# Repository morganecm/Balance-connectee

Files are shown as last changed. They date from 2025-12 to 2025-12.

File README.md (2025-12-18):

# Balance connectée

## Project description

L'objectif du projet est de concevoir une balance connectée permettant de peser une ruche d'abeille, afin que son propriétaire puisse suivre sa progression à distance : si le poids augmente, la ruche produit du miel.

## Groupe de projet 
Morgane CAM m1cam@enib.fr 

Reine CHAMES r24chames@enib.fr

Zakaria BOUMLINE z3boumli@enib.fr

Hassan ROUMANI h3rouman@enib.fr

Hussein IBRAHIM h3ibrahi@enib.fr

Aymane BAHSSAIN a3bahssa@enib.fr

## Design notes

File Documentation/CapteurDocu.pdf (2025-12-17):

Analyse et correction des erreurs de mesure d’une balance connectée

Avant de commencer le projet, cela sera utile si vous regardez des exemples de balances connectées afin d’avoir une idée globale du sujet.

Ensuite, le problème que j’ai rencontré est que les valeurs affichées ne sont pas correctes, car le capteur de force n’est pas bien positionné. Par conséquent, je capte des valeurs erronées.

Il est donc nécessaire de concevoir un design mécanique adéquat pour bien positionner les capteurs.

Après cela, vous pouvez tester le système, soit avec Arduino (comme je l’ai déjà fait, même si les valeurs reçues ne sont pas correctes), soit avec un ESP32.

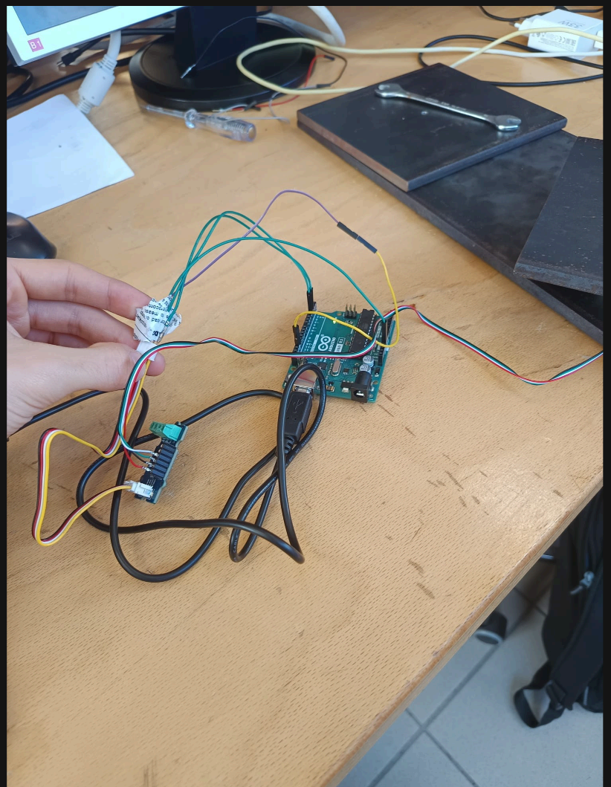
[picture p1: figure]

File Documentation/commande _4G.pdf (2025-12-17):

Connexion et test du module 4G sur Raspberry Pi

Dans le cadre de la connexion d’un module 4G au Raspberry Pi, plusieurs commandes ont été exécutées afin de vérifier la détection du module et d’établir la communication.

Tout d’abord, une connexion distante au Raspberry Pi a été réalisée via le protocole SSH :

ssh rpi@192.168.50.114

Ensuite, la commande suivante a permis de vérifier que le module 4G est bien reconnu par le système via le bus USB :

lsusb

Après cela, la présence des interfaces série créées par le module a été vérifiée :

ls /dev/ttyUSB*

Une fois le port série identifié, une communication directe avec le module 4G a été établie à l’aide de l’outil minicom, en se connectant au port série correspondant :

sudo minicom -D /dev/ttyUSB2

Enfin, une commande AT a été envoyée au module afin de vérifier l’état de la carte SIM :

AT+CPIN?

Cette commande permet de confirmer si la carte SIM est correctement insérée et prête à être utilisée.

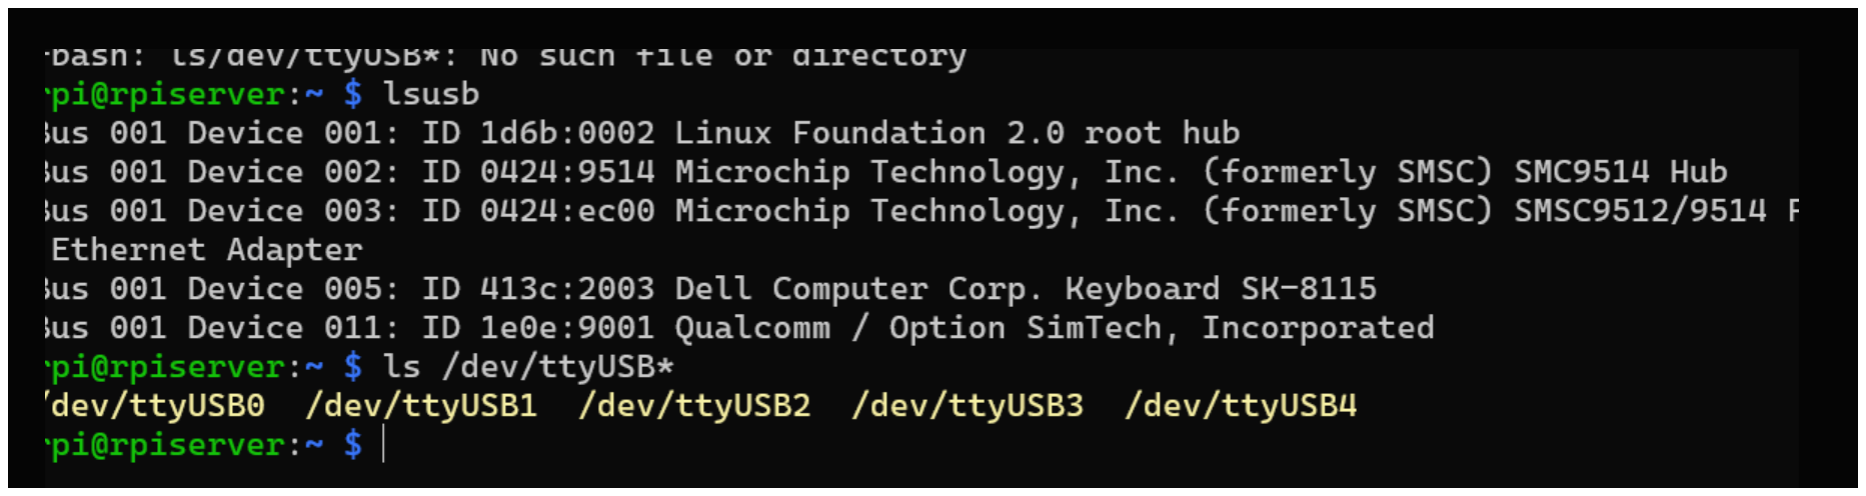
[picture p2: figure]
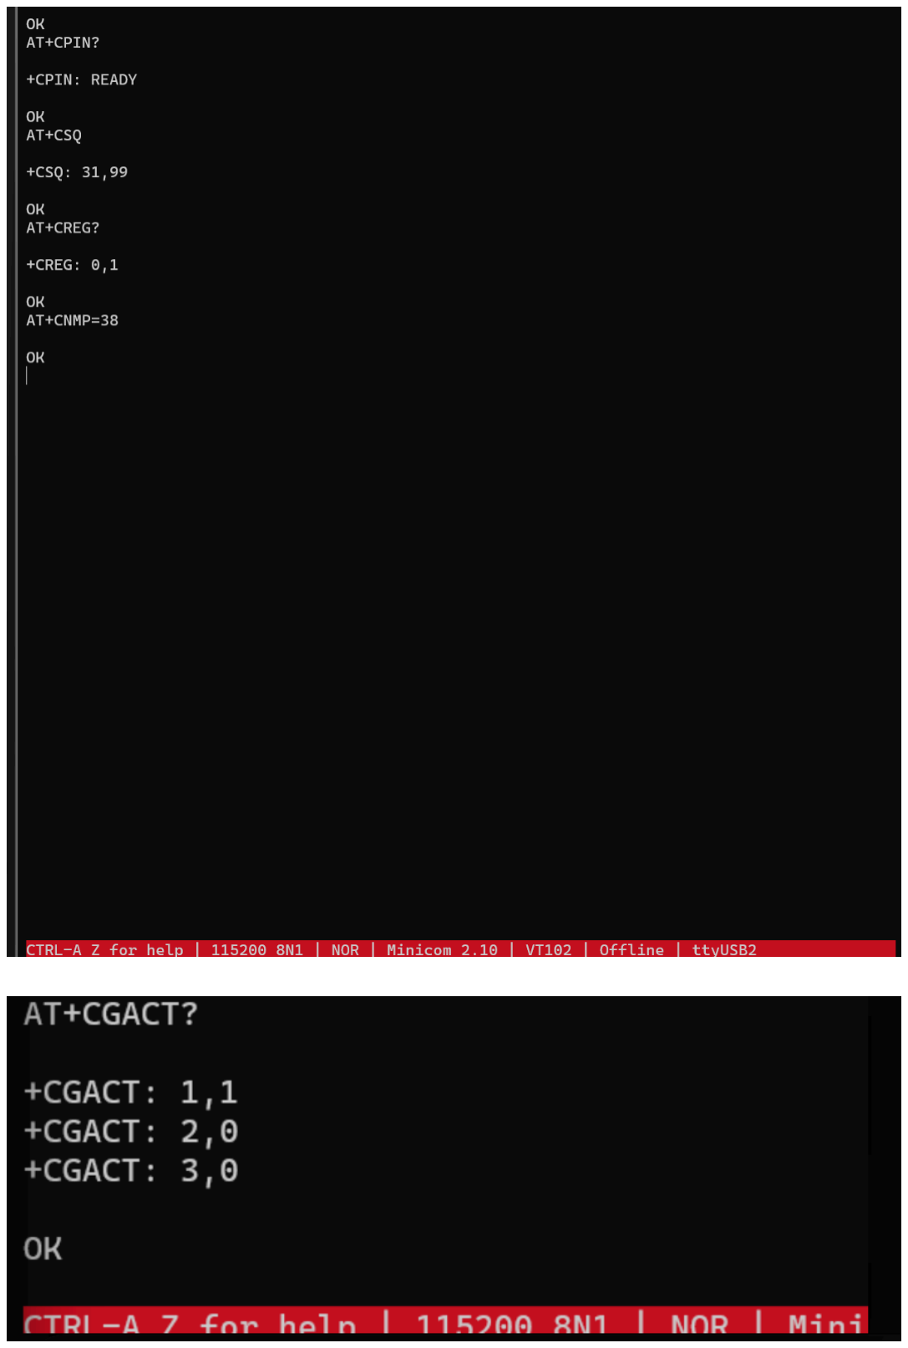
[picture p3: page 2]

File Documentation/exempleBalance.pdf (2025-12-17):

# Une ruche connectée

Au réseau SigFox, avec carte Arduino UNO

### SOMMAIRE

LES CONTRAINTES | page 3
L’ASSEMBLAGE DES ELEMENTS | page 5
LES CAPTEURS UTILISES | page 7
CHOISIR UN RESEAU | page 19
PROGRAMMER LES CAPTEURS | page 24
RECUPERER LES DONNEES | page 41
CHOISIR LES COMPOSANTS | page 51

Jean-Paul Bricard et Sébastien Marcilly

# Une ruche connectée

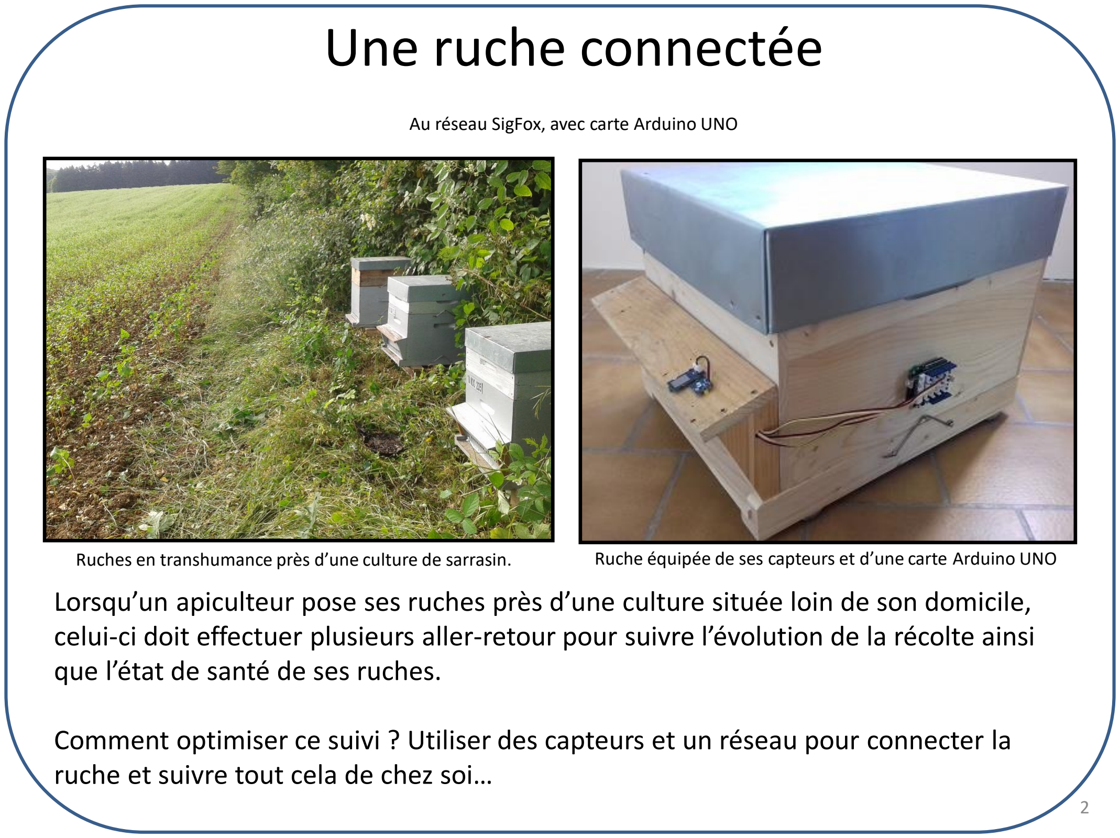
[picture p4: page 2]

Au réseau SigFox, avec carte Arduino UNO

Ruches en transhumance près d’une culture de sarrasin.
Lorsqu’un apiculteur pose ses ruches près d’une culture située loin de son domicile, celui-ci doit effectuer plusieurs aller-retour pour suivre l’évolution de la récolte ainsi que l’état de santé de ses ruches.

Comment optimiser ce suivi ? Utiliser des capteurs et un réseau pour connecter la ruche et suivre tout cela de chez soi…

Ruche équipée de ses capteurs et d’une carte Arduino UNO

# Une ruche connectée

Les contraintes liées à une ruche

Diagramme des cas d’utilisation

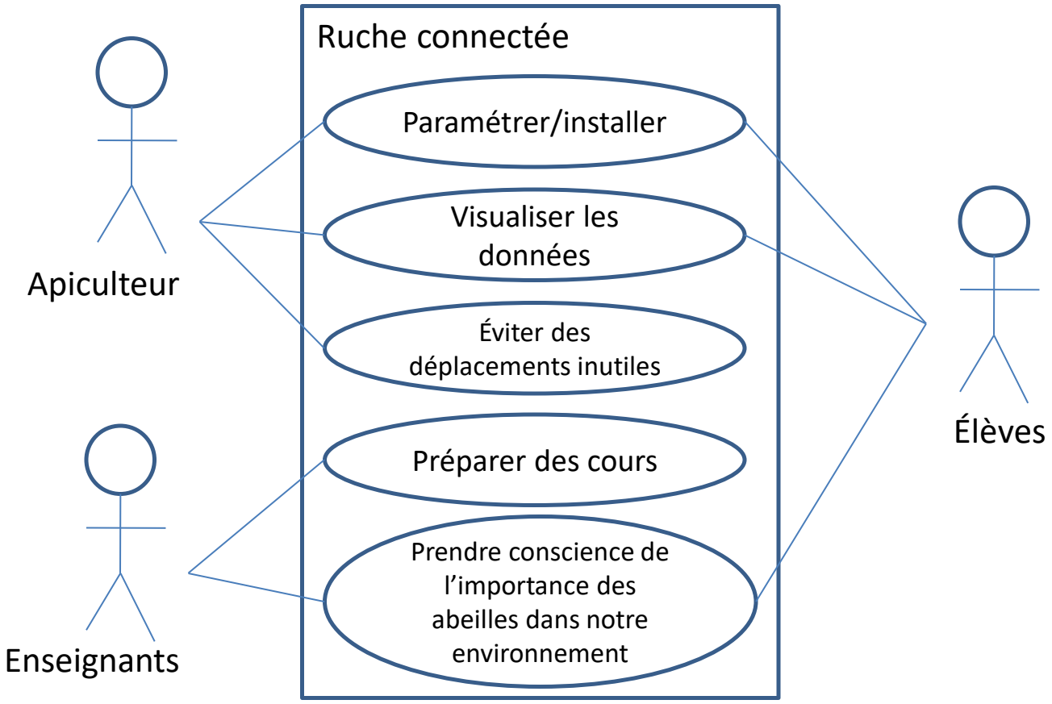
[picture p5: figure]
Ruche connectée; Paramétrer/installer; Visualiser les données; Éviter des déplacements inutiles; Préparer des cours; Prendre conscience de l’importance des abeilles dans notre environnement; Élèves; Apiculteur; Enseignants

# Une ruche connectée

Les contraintes liées à une ruche

Diagramme de contexte; Ruche connectée; Doit pouvoir obtenir les données des capteurs et les envoyer sur un réseau sans fil.; Météo; Doit résister aux intempéries et aux variations de température; Énergie; Doit être autonome et économique en énergie; Communication; Doit utiliser un réseau permettant une connexion en pleine nature; Abeilles; Doit respecter les abeilles; Environnement; Doit respecter le développement durable; Apiculteur; Permet à l’apiculteur de connaître les valeurs des capteurs de la ruche et l’état de santé de la colonie

# Une ruche connectée

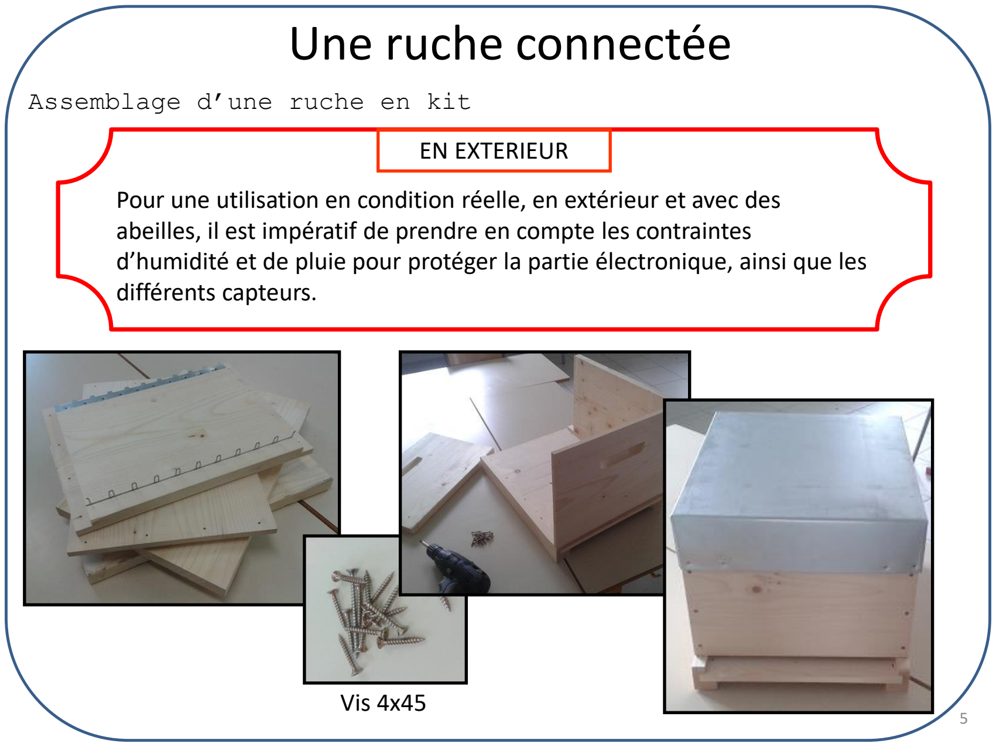
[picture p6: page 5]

Assemblage d’une ruche en kit

Vis 4x45

EN EXTERIEUR

Pour une utilisation en condition réelle, en extérieur et avec des abeilles, il est impératif de prendre en compte les contraintes d’humidité et de pluie pour protéger la partie électronique, ainsi que les différents capteurs.

# Une ruche connectée

Assemblage du auvent de la ruche

Perçage des cotés pour la fixation sur la ruche. Vis 4x60

Ø 8, profondeur 20mm pour passer la tête de vis,
Ø 4, traversant pour passer la vis

Fixation du auvent sur les cotés. Vis 4x30

# Une ruche connectée

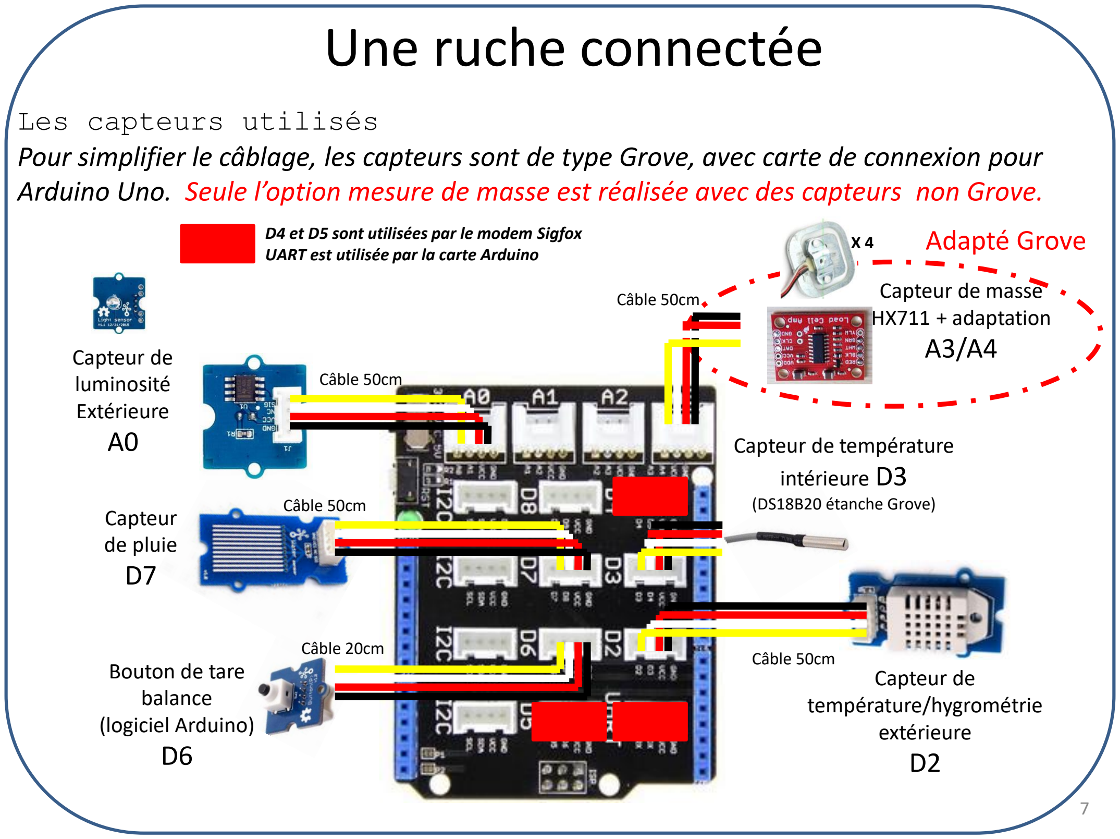
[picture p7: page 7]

Capteur de
luminosité
Extérieure
A0

Capteur de
température/hygrométrie
extérieure
D2

Capteur de masse
HX711 + adaptation
A3/A4

Adapté Grove

Capteur de température
intérieure D3

(DS18B20 étanche Grove)
Capteur
de pluie
D7

Câble 50cm

Câble 50cm

Câble 50cm

Câble 50cm

Les capteurs utilisés
Pour simplifier le câblage, les capteurs sont de type Grove, avec carte de connexion pour Arduino Uno. Seule l’option mesure de masse est réalisée avec des capteurs non Grove.

X 4

Bouton de tare
balance
(logiciel Arduino)
D6

Câble 20cm

D4 et D5 sont utilisées par le modem Sigfox UART est utilisée par la carte Arduino

# Une ruche connectée

La carte Arduino UNO et la carte de connexion Grove

# Une ruche connectée

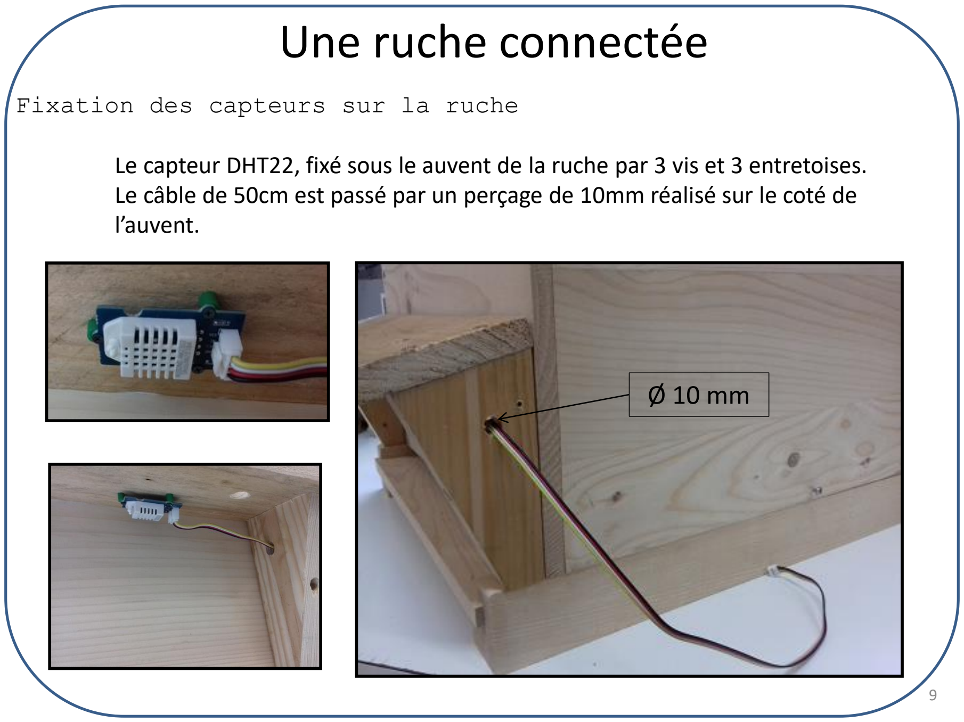
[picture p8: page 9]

Fixation des capteurs sur la ruche

Le capteur DHT22, fixé sous le auvent de la ruche par 3 vis et 3 entretoises. Le câble de 50cm est passé par un perçage de 10mm réalisé sur le coté de l’auvent.

Ø 10 mm

# Une ruche connectée

Fixation des capteurs sur la ruche

Le capteur de pluie, fixé sur le auvent de la ruche par 3 vis et 3 entretoises.
Une extrémité du câble de 50cm est passée par un perçage de 13mm réalisé sur le dessus de l’auvent. L’autre extrémité passe par le perçage de 10mm réalisé sur le coté de l’auvent.

Ø 13 mm

# Une ruche connectée

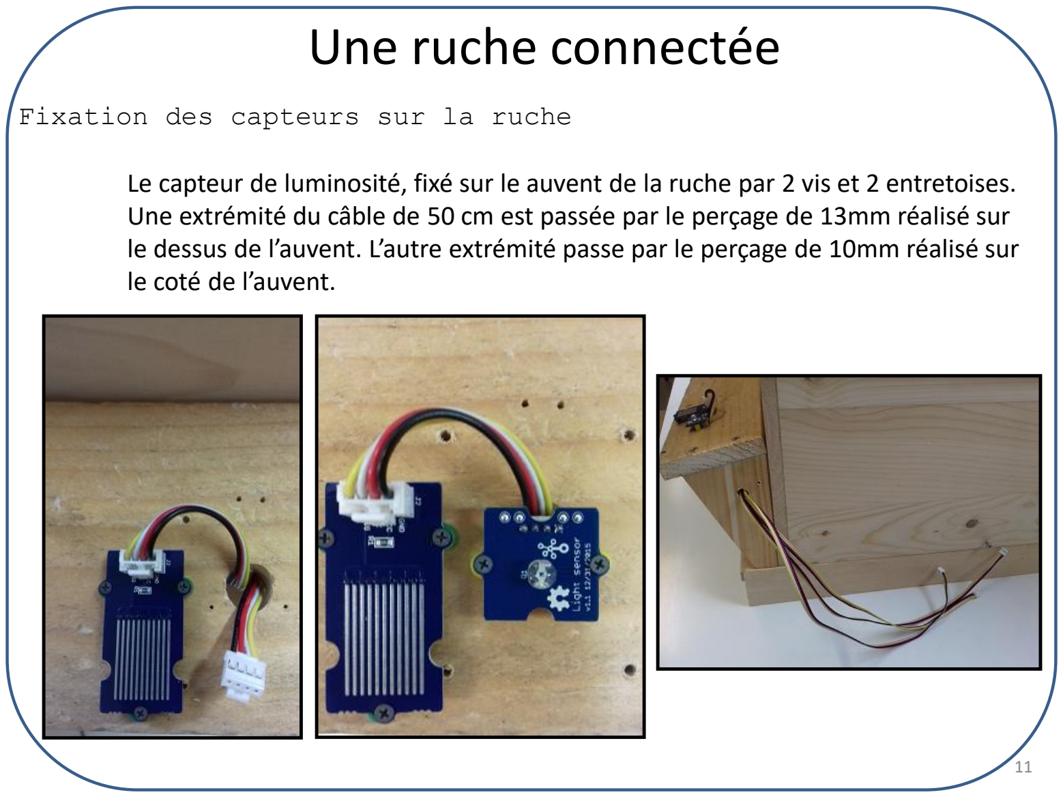
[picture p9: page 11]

Fixation des capteurs sur la ruche

Le capteur de luminosité, fixé sur le auvent de la ruche par 2 vis et 2 entretoises. Une extrémité du câble de 50 cm est passée par le perçage de 13mm réalisé sur le dessus de l’auvent. L’autre extrémité passe par le perçage de 10mm réalisé sur le coté de l’auvent.

# Une ruche connectée

Fixation des capteurs sur la ruche

Le capteur de température intérieure, est à insérer dans la ruche.
Un perçage de 8mm est réalisé dans le couvre cadres pour permettre le passage du capteur entre 2 cadres de la ruche sans gêner la pose du toit.

Ø 8 mm
Entre 2 cadres

# Une ruche connectée

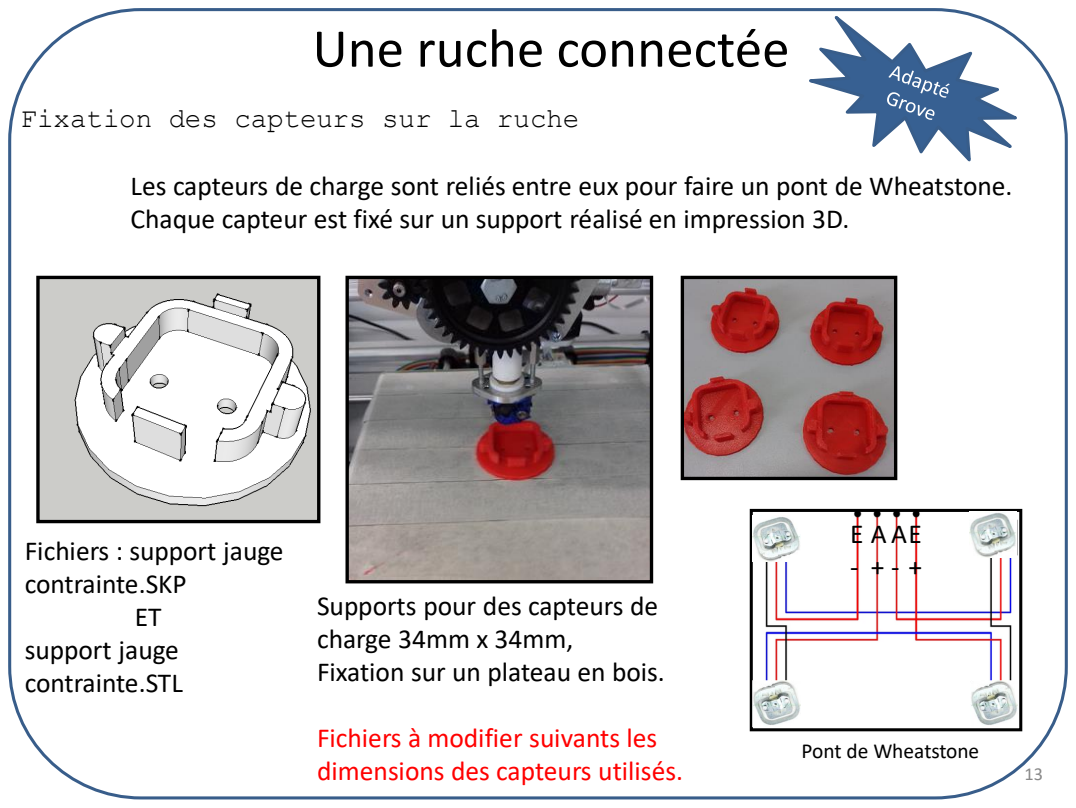
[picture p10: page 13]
ET support jauge contrainte.STL

Fixation des capteurs sur la ruche

Les capteurs de charge sont reliés entre eux pour faire un pont de Wheatstone.
Chaque capteur est fixé sur un support réalisé en impression 3D.

Fichiers : support jauge
contrainte.SKP

Supports pour des capteurs de
charge 34mm x 34mm,
Fixation sur un plateau en bois.

Fichiers à modifier suivants les
dimensions des capteurs utilisés.

Pont de Wheatstone

# Une ruche connectée

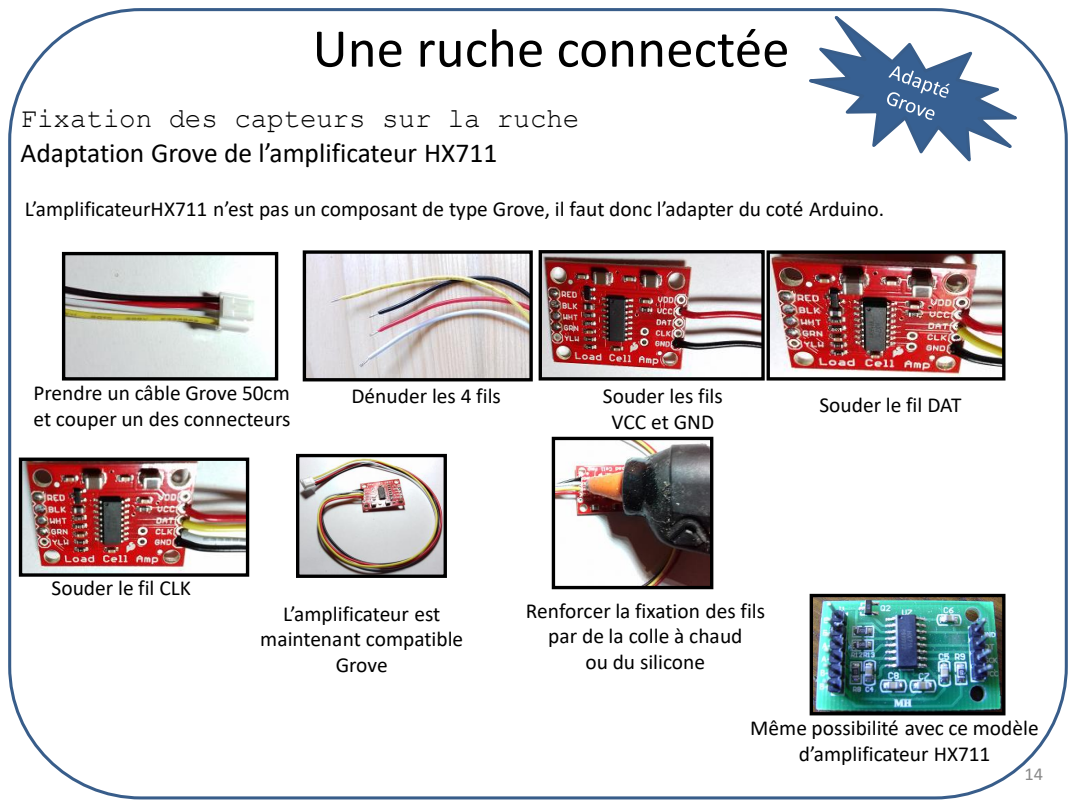
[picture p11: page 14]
Dénuder les 4 fils; Souder les fils; L’amplificateur est maintenant compatible Grove

Fixation des capteurs sur la ruche
Adaptation Grove de l’amplificateur HX711

L’amplificateurHX711 n’est pas un composant de type Grove, il faut donc l’adapter du coté Arduino.

Prendre un câble Grove 50cm
et couper un des connecteurs

Souder le fil DAT

VCC et GND

Souder le fil CLK

Renforcer la fixation des fils
par de la colle à chaud
ou du silicone

Même possibilité avec ce modèle
d’amplificateur HX711

# Une ruche connectée

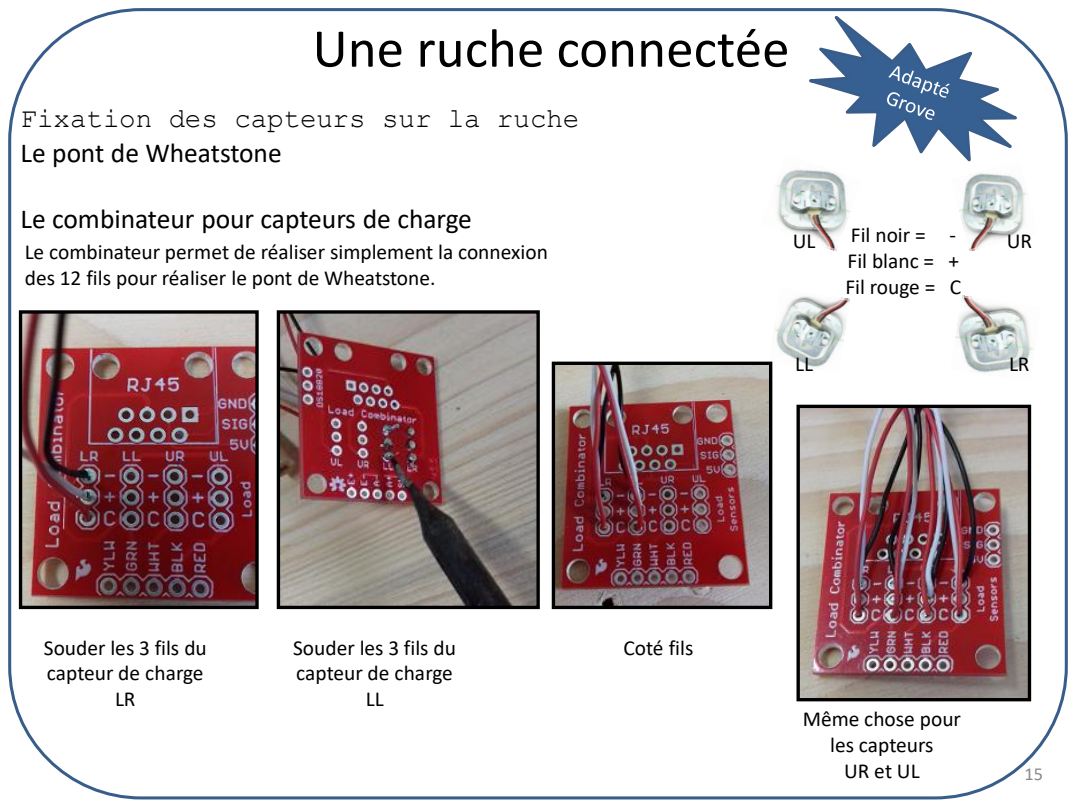
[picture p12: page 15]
UR Fil noir = -; Fil blanc = + Fil rouge = C; Coté fils

Fixation des capteurs sur la ruche
Le pont de Wheatstone

Le combinateur pour capteurs de charge
Le combinateur permet de réaliser simplement la connexion
des 12 fils pour réaliser le pont de Wheatstone.

Souder les 3 fils du
capteur de charge

Même chose pour
les capteurs

# Une ruche connectée

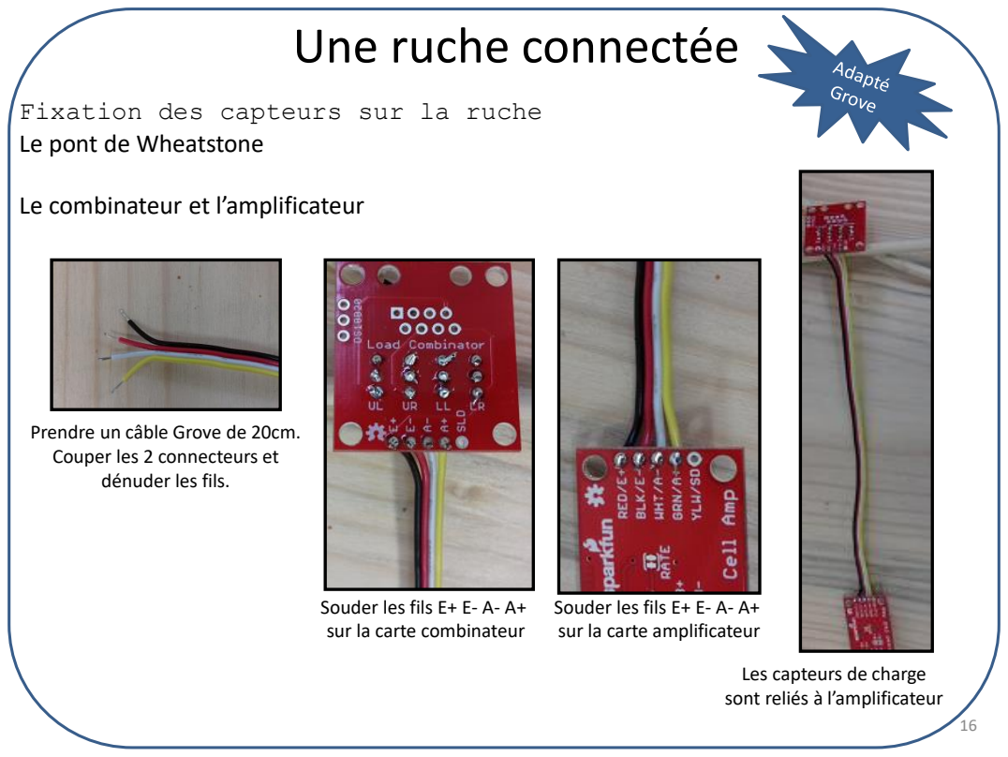
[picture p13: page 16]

Fixation des capteurs sur la ruche
Le pont de Wheatstone

Le combinateur et l’amplificateur

Prendre un câble Grove de 20cm.
Couper les 2 connecteurs et
dénuder les fils.

Souder les fils E+ E- A- A+
sur la carte combinateur

sur la carte amplificateur

Les capteurs de charge
sont reliés à l’amplificateur

# Une ruche connectée

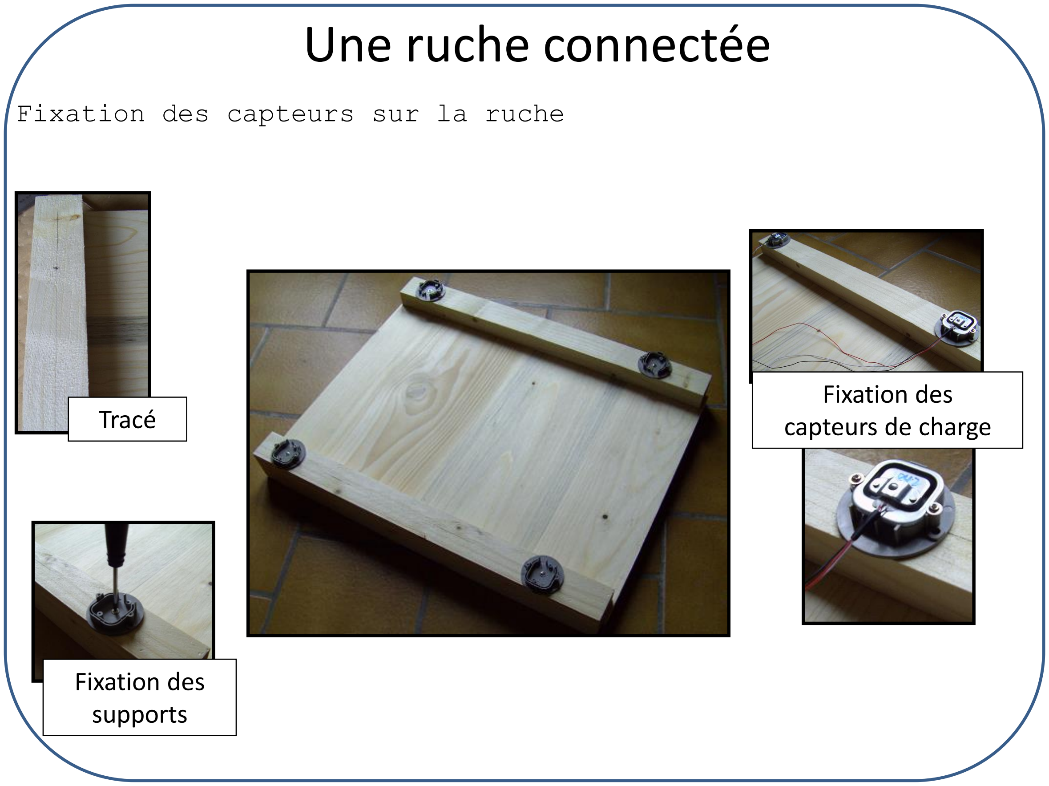
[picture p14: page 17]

Tracé

Fixation des
supports

Fixation des
capteurs de charge

Fixation des capteurs sur la ruche

# Une ruche connectée

Fixe câble

Câble fixé

Pour une utilisation en
extérieur, à placer dans
une boite étanche

Pour une utilisation en
extérieur, protéger les
connexions avec du
silicone.

Fixation des capteurs sur la ruche

Possibilité de placer
les fils des capteurs de
charge dans une gaine
de câble téléphonique,
préalablement fendue
sur la longueur.

Choisir un réseau pour connecter la ruche

# Une ruche connectée

Choisir le bon réseau est un point essentiel pour suivre le travail des abeilles à distance. Voici un comparatif de différentes solutions :
Comparatif des réseaux
Réseau | Avantages | Inconvénient
Sigfox | Consommation réduite, longue portée | Réseau nouveau
GSM | Consommation moyenne Longue portée | Coût élevé
Ethernet | Fiabilité du transfert, Faible coût | Filaire
Zigbee | Consommation réduite, Faible coût | Petite portée
Wifi | Pas d’abonnement | Coût élevé, Petite portée, modem
Bluetooth | Faible coût | Petite portée

Le réseau SIGFOX

Le choix s’est arrêté sur le réseau Sigfox pour plusieurs critères.

Sigfox est une société française, près de Toulouse.
Sigfox a créé un réseau longue portée et à bas débit qui permet la communication de données de taille réduite entre les appareils connectés sans passer par un téléphone mobile. C’est le tout premier réseau de l’IoT ou IdO (Internet des Objets) à avoir été mis en place.

Cette connexion à bas débit entre les objets connectés est possible grâce à sa technologie radio (UNB). Peu énergivore, elle utilise des bandes de fréquence libre de droit disponible pour le monde entier, comme les bandes ISM (Bande industrielle, scientifique et médicale). En Europe, il s’agit de l’ISL à 868 MHz. L’entreprise revendique une couverture de 92 % de la population française.
Le réseau SigFox affiche des performances similaires dans toutes les villes où il est implanté.

Source : http://www.objetconnecte.com/tout-savoir-sur-sigfox/

# Une ruche connectée

La carte AKERU
ou … Comment utiliser le réseau SigFox … ?

http://www.snootlab.com/shields-snootlab/889-akene-v1-fr.html

L’utilisation du réseau SIGFOX se fait grâce à un abonnement au prix de 15€/an (inclus dans le prix d’achat de la carte modem).

Cet abonnement (à renouveler chaque année) permet d’envoyer au maximum 140 messages par jour pendant 1 an. Ce qui revient à 1 message par 10 min.

Cette carte est basée sur une carte Arduino Uno.

Il faut toujours brancher l'antenne avant d'alimenter la carte (sinon l'énergie normalement dissipée
dans l'antenne sera convertie en chaleur dans le modem et peut le détruire).

Les broches D4 et D5 de la carte Arduino lui sont réservées (Rx/Tx)

# Une ruche connectée

http://forum.snootlab.com/viewforum.php?f=51

Toutes les explications techniques sont sur le forum officiel :

Le Shield AKENE pour Arduino Uno
ou … Comment utiliser le réseau SigFox … ?

http://www.snootlab.com/shields-snootlab/889-akene-v1-fr.html

L’utilisation du réseau SIGFOX se fait grâce à un abonnement au prix de 15€/an (inclus dans le prix d’achat de la carte modem).

Cet abonnement (à renouveler chaque année) permet d’envoyer au maximum 140 messages par jour pendant 1 an. Ce qui revient à 1 message par 10 min.

Cette carte se monte sur les connecteurs de la carte Arduino.

Le câblage des Entrées/Sorties se fait de la même manière que sur la carte Arduino seule. Il faut toujours brancher l'antenne avant d'alimenter la carte (sinon l'énergie normalement dissipée
dans l'antenne sera convertie en chaleur dans le modem et peut le détruire).

Les broches D4 et D5 de la carte Arduino lui sont réservées (Rx/Tx) Transfert des programmes AVEC le shield monté sur la carte Arduino UNO

# Une ruche connectée

http://forum.snootlab.com/viewforum.php?f=51

Toutes les explications techniques sont sur le forum officiel :

Le SHIELD ARM-N8-SIGFOX pour Arduino Uno
ou … Comment utiliser le réseau SigFox … ?

https://www.lextronic.fr/P37770-shield-radio-arm-n8-sigfox.html

Cette carte propose les mêmes fonctionnalités que le Shield AKENE
MAIS le modem utilise les Rx/Tx (D0/D1 ) de la carte Arduino Uno pour communiquer. Pour transférer le programme, il faut impérativement retirer le Shield et le remettre en place après.

# Une ruche connectée

Le choix s’est tourné vers le shield AKENE,

Snootlab permet un achat par les établissements scolaires Le laboratoire est déjà équipé de cartes Arduino Uno, Pas de dépose/repose du shield lors de la programmation

# Une ruche connectée

Programmation des capteurs avec les logiciels

Logiciel Ardublock éducation 1.3
Sont uniquement programmables avec cette version : le capteur de température HD (DHT22), le capteur de lumière et le capteur de pluie.

Logiciel Mblock 3.4.11 + extension TS GROVE 1.3
Mode connecté
Sont uniquement programmables avec cette extension : le capteur de température HD (DHT22), le capteur de lumière et le capteur de pluie.
Mode téléversé
Pour programmer le capteur de température intérieure (DS18B20), le capteur de masse ainsi que le shield AKENE (modem SigFox), il faut ajouter l’extension Ruche GROVE et les bibliothèques Arduino. Cette extension permet de relever les valeurs des capteurs de la ruche et de les envoyer sur le réseau SigFox.
Visualisation de ces valeurs uniquement sur le tableau de bord Actoboard.

Pour aller plus loin, le logiciel Arduino 1.6.9
L’ensemble des capteurs de la ruche ainsi que le modem sont programmables en lignes de code. Les valeurs sont affichées par le moniteur série et/ou sur le tableau de bord Actoboard. Il faut ajouter les bibliothèques Arduino.

# Une ruche connectée

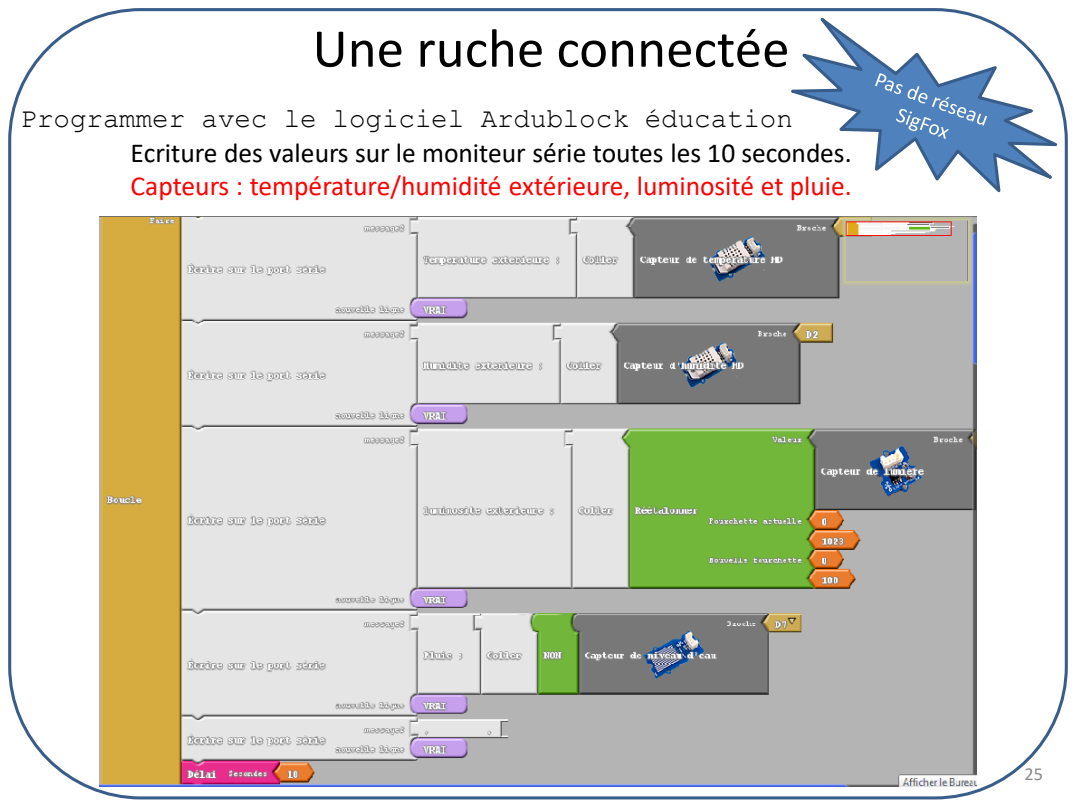
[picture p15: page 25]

Programmer avec le logiciel Ardublock éducation

Ecriture des valeurs sur le moniteur série toutes les 10 secondes.
Capteurs : température/humidité extérieure, luminosité et pluie.

# Une ruche connectée

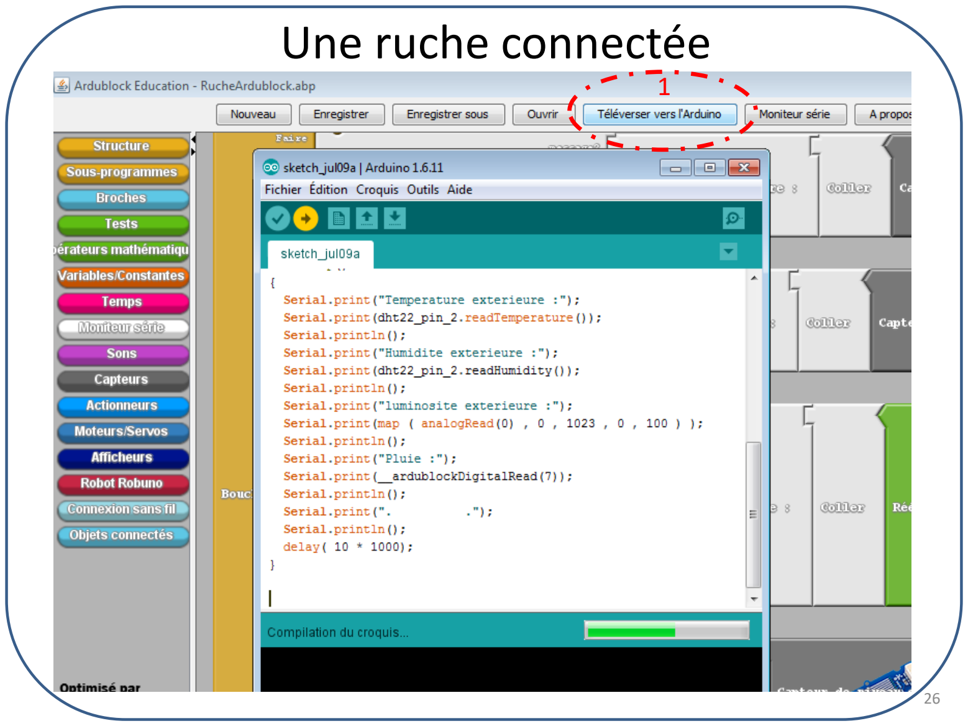
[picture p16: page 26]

1

# Une ruche connectée

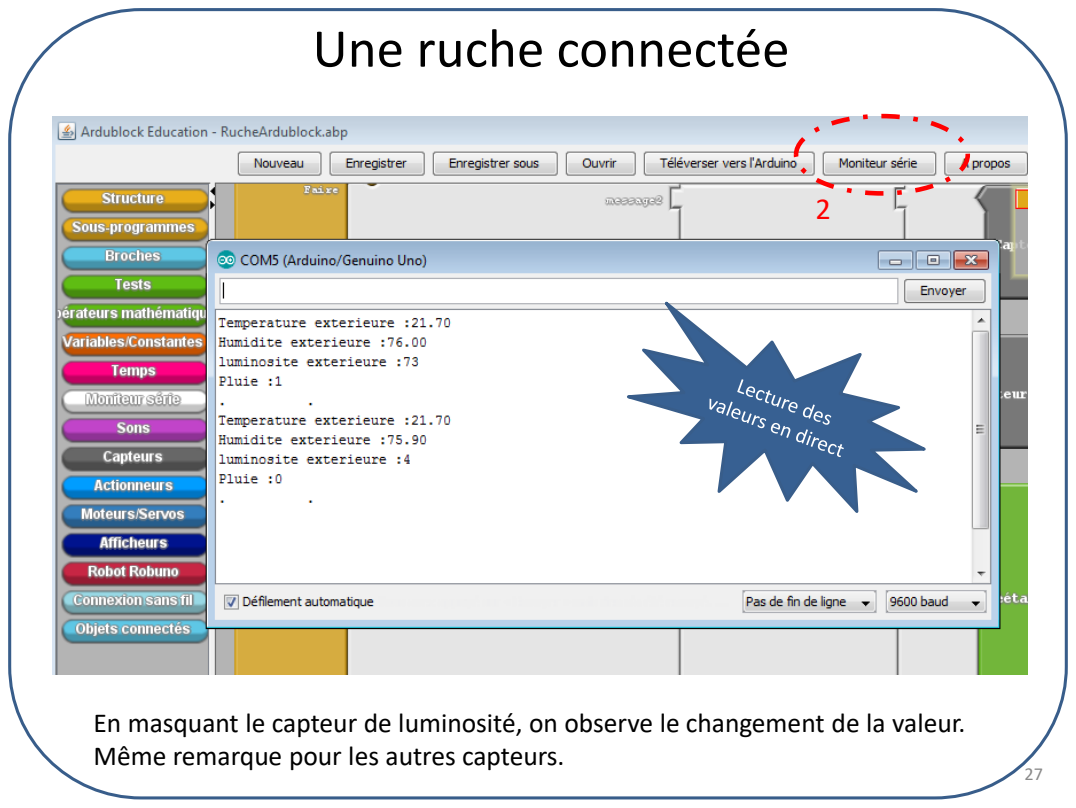
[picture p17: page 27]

En masquant le capteur de luminosité, on observe le changement de la valeur.
Même remarque pour les autres capteurs.

# Une ruche connectée

Logiciel IDE Arduino 1.6.9 et ajout des bibliothèques
Pour rendre la bibliothèque du shield Akene compatible avec Mblock, Il faut remplacer le dossier Arduino du répertoire mblock par le dossier Arduino contenu dans le dossier « A remplacer dans Mblock ».

Ce remplacement permet de mettre Arduino version 1.6.9, au lieu de la version 1.6.5 installée par Mblock.

# Une ruche connectée

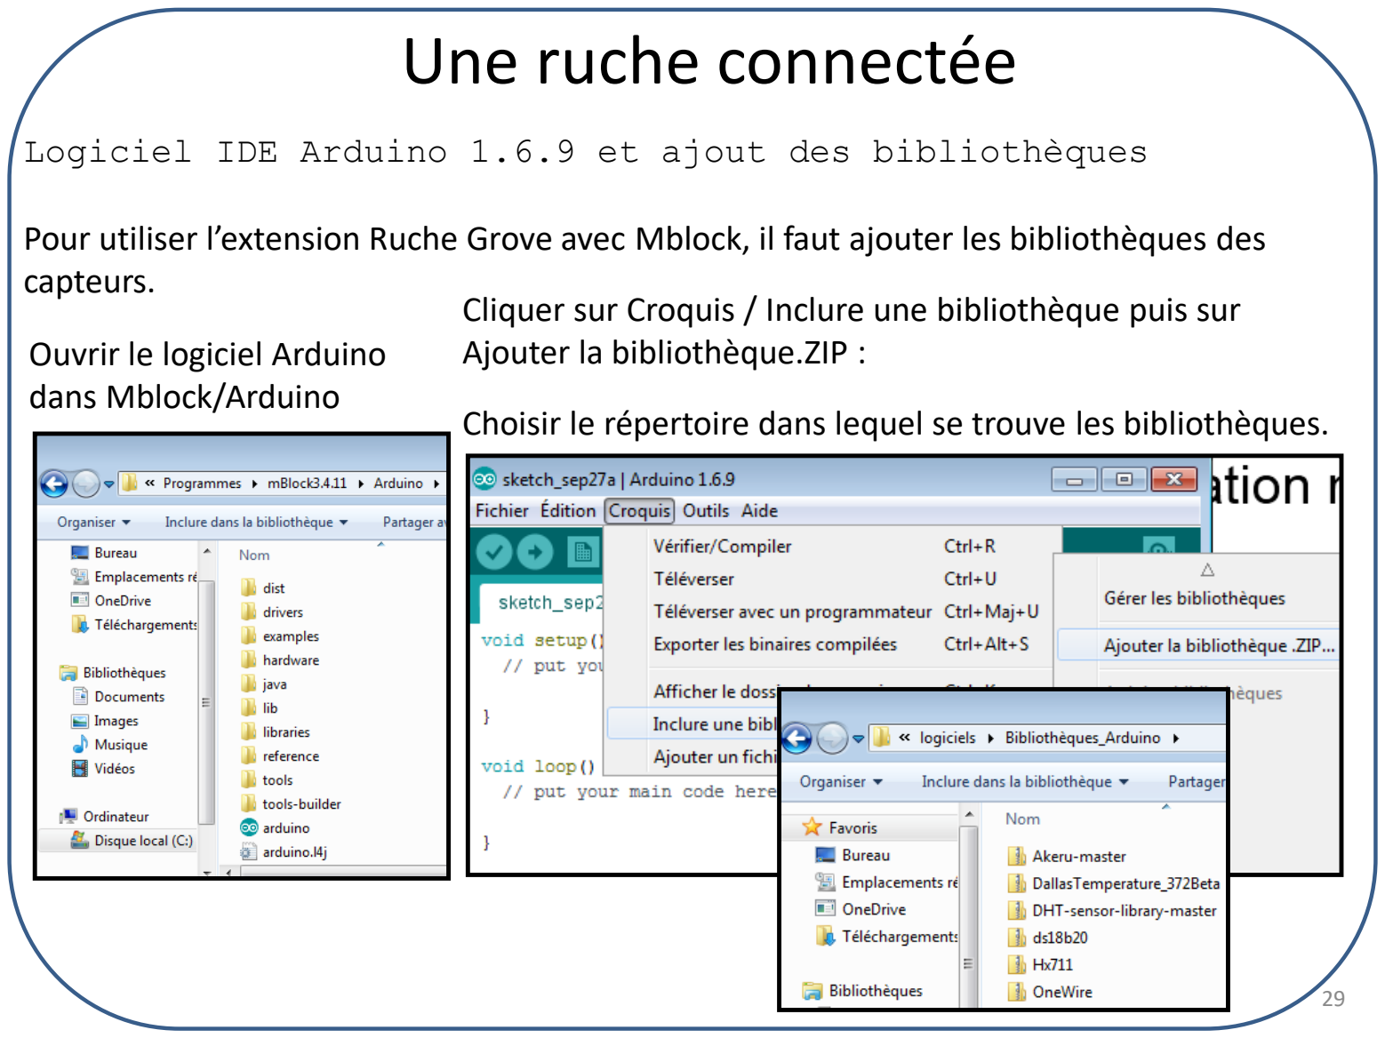
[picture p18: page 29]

Ouvrir le logiciel Arduino dans Mblock/Arduino

Cliquer sur Croquis / Inclure une bibliothèque puis sur Ajouter la bibliothèque.ZIP :

Choisir le répertoire dans lequel se trouve les bibliothèques.

Logiciel IDE Arduino 1.6.9 et ajout des bibliothèques

Pour utiliser l’extension Ruche Grove avec Mblock, il faut ajouter les bibliothèques des capteurs.

# Une ruche connectée

Ajout des extensions Mblock
Ajouter l’extension TS GROVE 1.3

Sélectionner l’extension
TS (.ZIP)

Cliquer sur :
Ajouter

Sélectionner (.ZIP)

Cliquer sur :
Gérer les extensions

# Une ruche connectée

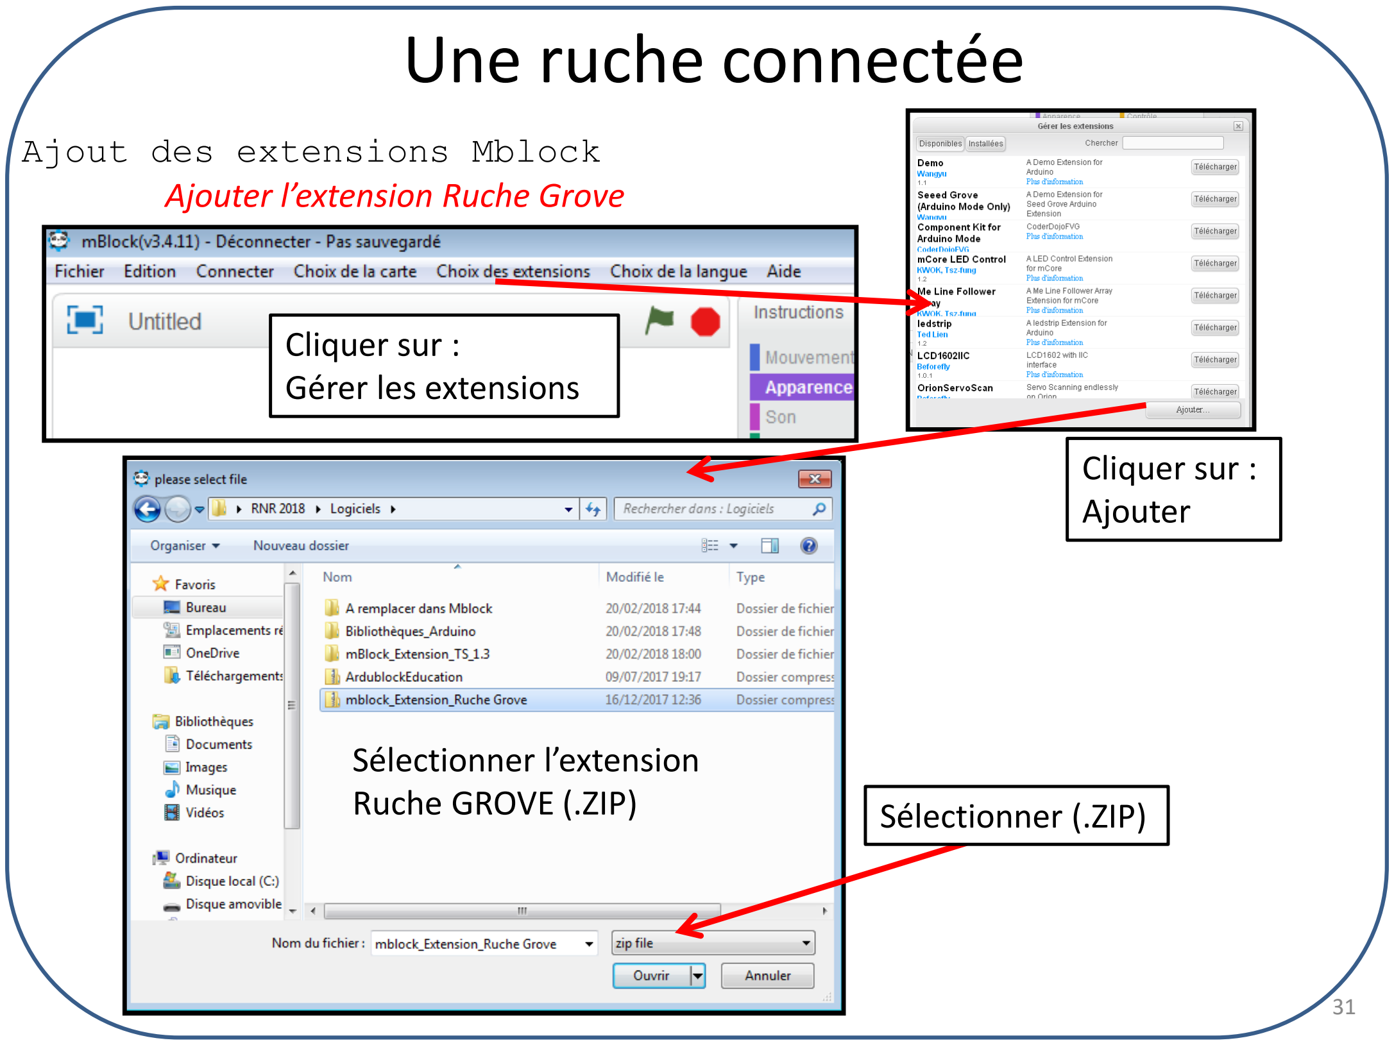
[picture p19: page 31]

Ajout des extensions Mblock
Ajouter l’extension Ruche Grove

Sélectionner l’extension
Ruche GROVE (.ZIP)

Cliquer sur :
Ajouter

Sélectionner (.ZIP)

Cliquer sur :
Gérer les extensions

# Une ruche connectée

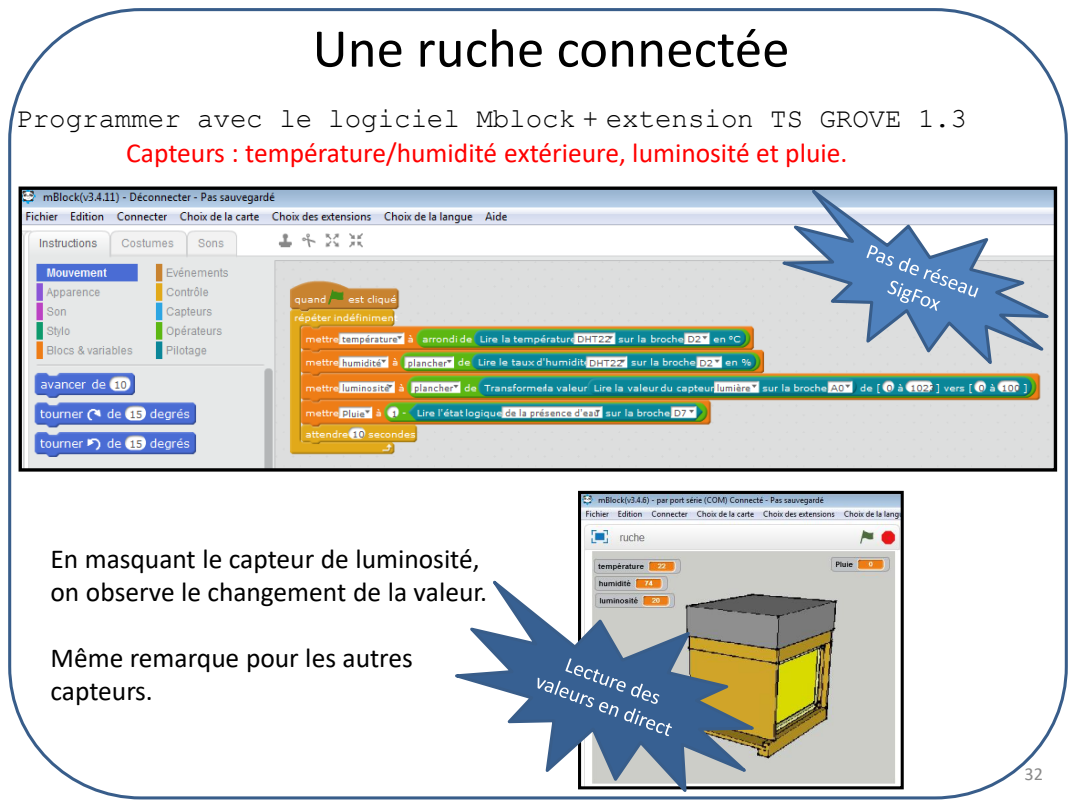
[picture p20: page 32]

Programmer avec le logiciel Mblock + extension TS GROVE 1.3

Capteurs : température/humidité extérieure, luminosité et pluie.

En masquant le capteur de luminosité,
on observe le changement de la valeur.

Même remarque pour les autres
capteurs.

# Une ruche connectée

L’extension Ruche GROVE pour Mblock
Utilisation du réseau SigFox avec Shield AKENE ou carte AKERU

Génère le code Arduino

Initialise le modem
suivant la carte utilisée

Lecture DHT22, sur D2

Lecture DS18B20, sur D3

Lecture capteur luminosité, sur A0

Lecture capteur de pluie, sur D7

Lecture capteur de masse, sur A3

# Une ruche connectée

Envoi capteur DHT22

Envoi capteurs pluie et luminosité et DS18B20 et DHT22 et masse

Le code associé à l’envoi est à recopier dans le format data du tableau de bord Actoboard pour visualiser les valeurs envoyées.

Envoi capteur luminosité

Envoi capteur DS18B20

Envoi capteur pluie

Envoi capteur de masse

Envoi capteurs pluie et luminosité et DS18B20 et DHT22

Envoi capteurs luminosité et DS18B20 et DHT22

# Une ruche connectée

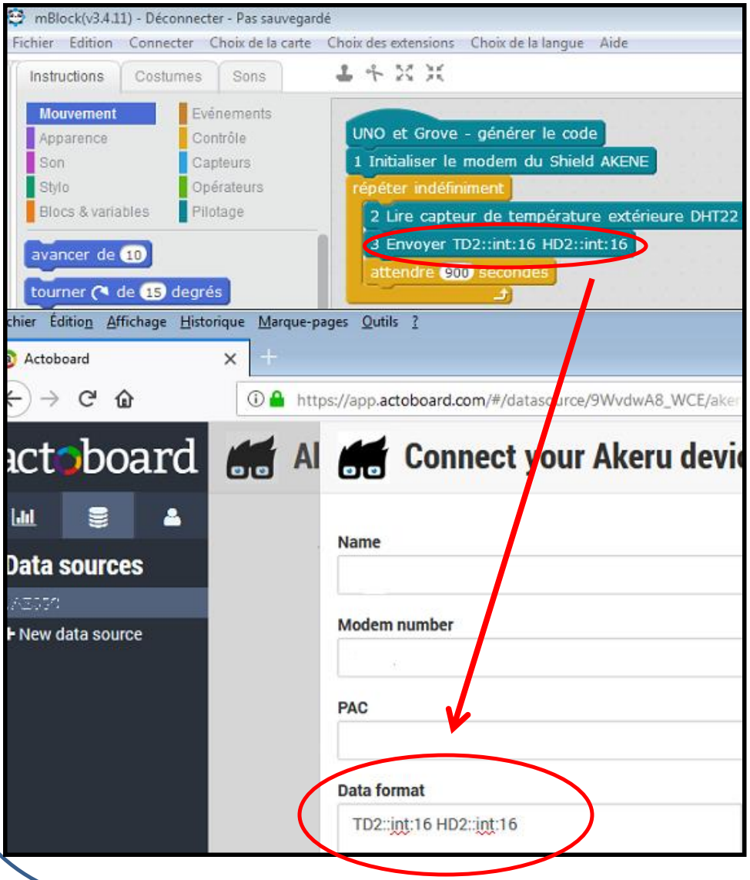
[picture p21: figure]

Correspondance entre la
commande « Envoyer » Mblock et Data format dans Actoboard

# Une ruche connectée

Programme Mblock + extension Ruche GROVE
Utilisation du réseau SigFox avec le Shield AKENE et abonnement Actoboard activé

Envoi des valeurs du capteur DHT22

Envoi des valeurs du capteur de pluie

La ligne de code Data format est complétée sur Actoboard.

Attente de 15min entre chaque envoi (60 x 15 =900)

# Une ruche connectée

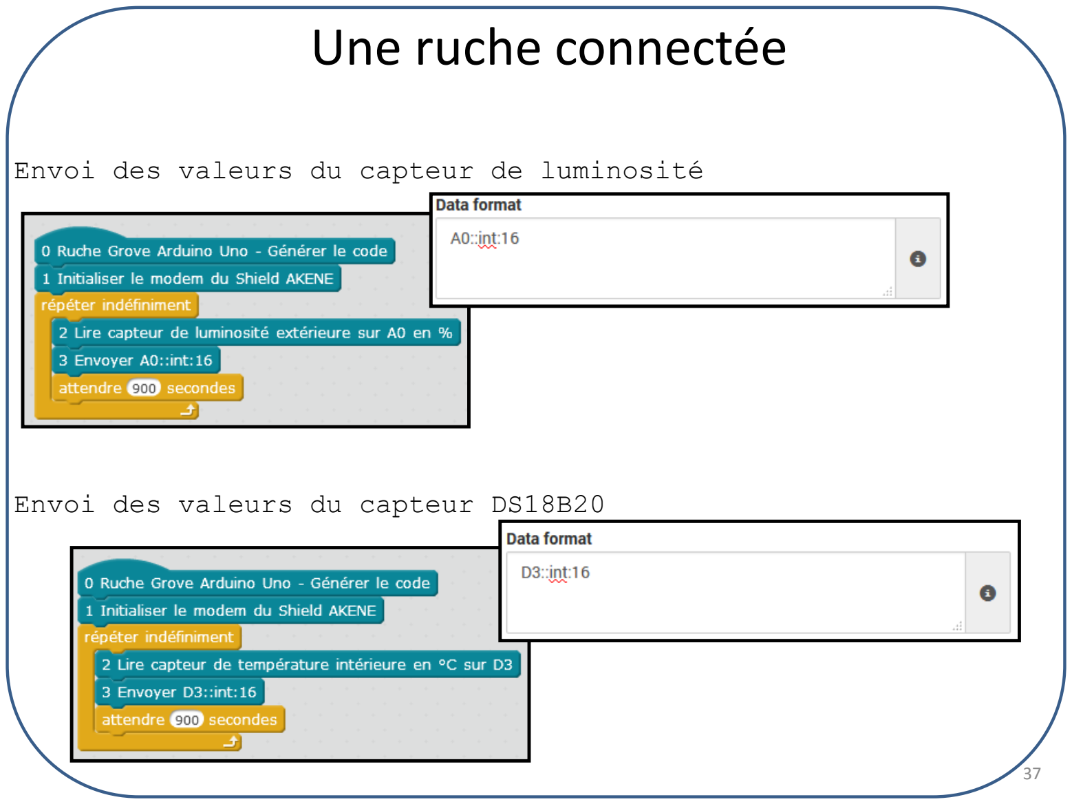
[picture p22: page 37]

Envoi des valeurs du capteur de luminosité

Envoi des valeurs du capteur DS18B20

# Une ruche connectée

Envoi des valeurs du capteur de luminosité et du capteur DHT22

Envoi des valeurs du capteur de masse

La tare de la balance se fait au début du programme. Ensuite par reset de la carte.

# Une ruche connectée

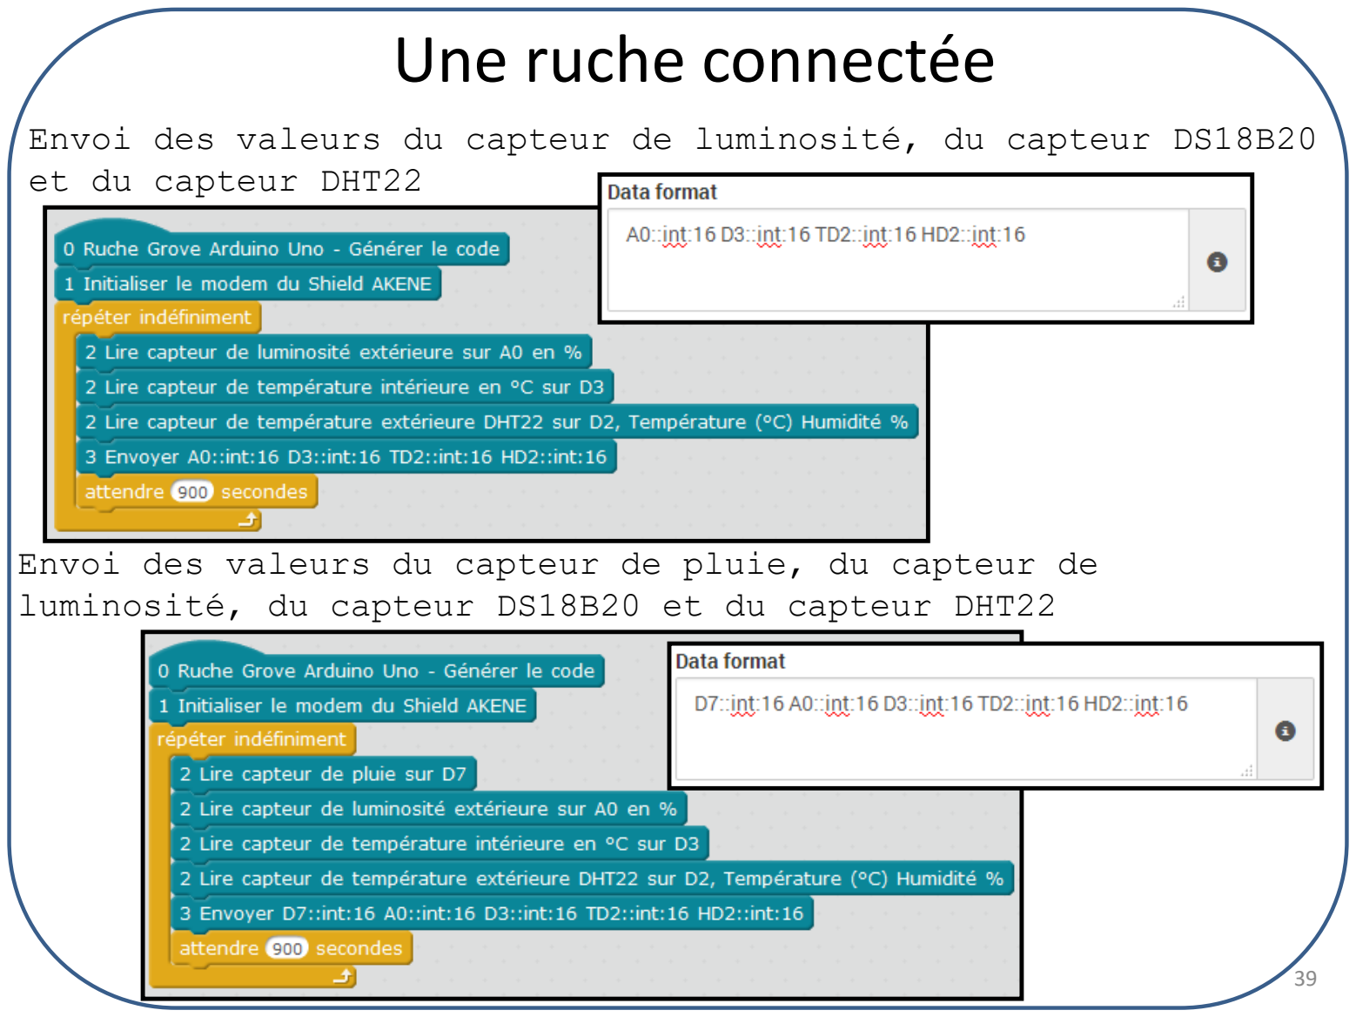
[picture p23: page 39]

Envoi des valeurs du capteur de luminosité, du capteur DS18B20 et du capteur DHT22

Envoi des valeurs du capteur de pluie, du capteur de luminosité, du capteur DS18B20 et du capteur DHT22

# Une ruche connectée

Envoi des valeurs du capteur de pluie, du capteur de luminosité, du capteur DS18B20, du capteur DHT22 et du capteur de masse

La tare de la balance se fait au début du programme. Ensuite par reset de la carte.

Le tableau de bord Actoboard | https://app.actoboard.com/#/
Aide du site | http://www.actoboard.com/docs/

# Une ruche connectée

Créer un compte pour avoir accès aux données envoyées sur le réseau Sigfox par votre modem. Avec le code promo 4K3RU-SN00TL4B

# Une ruche connectée

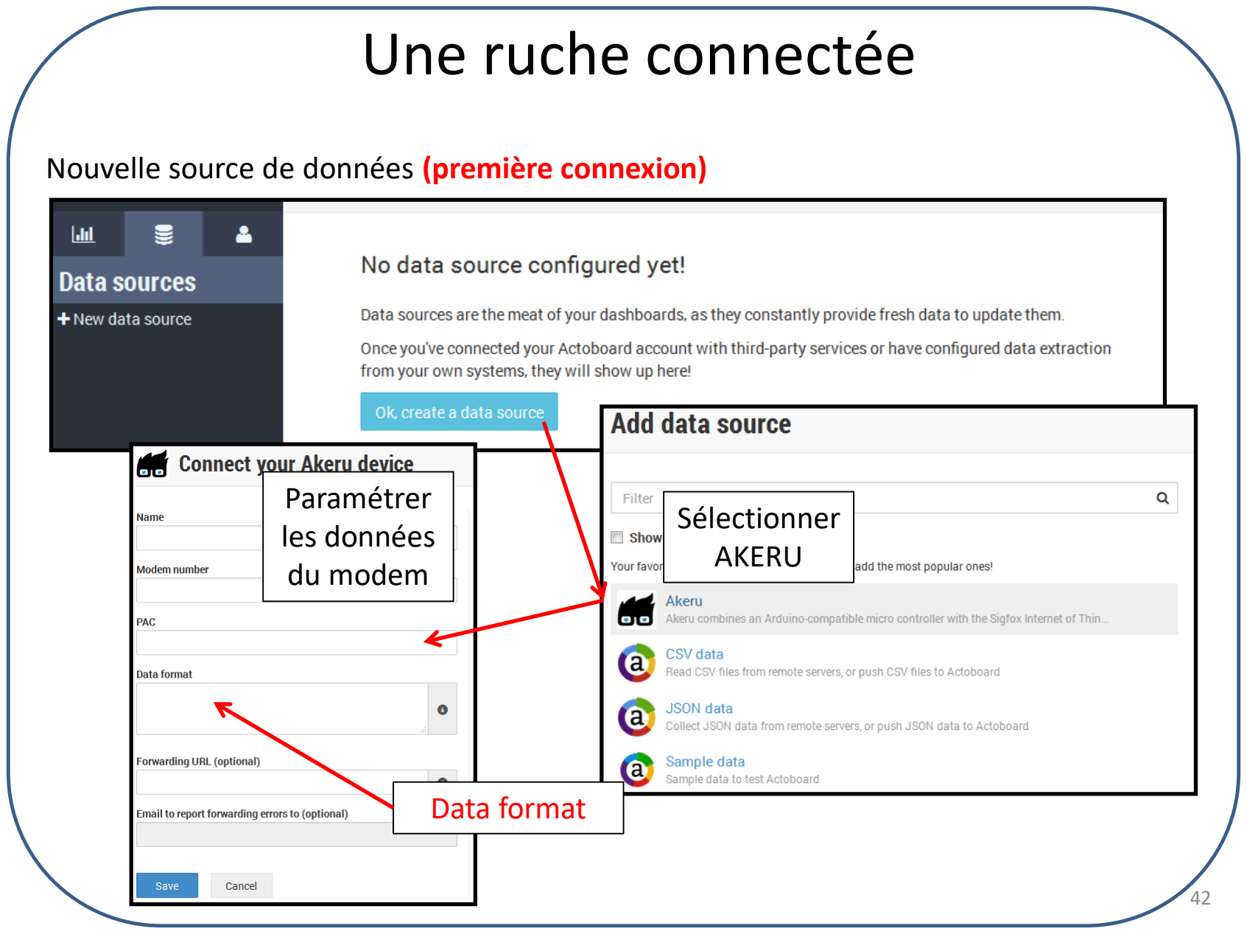
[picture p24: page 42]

Nouvelle source de données (première connexion)

Sélectionner
AKERU

Paramétrer
les données
du modem

Data format

# Une ruche connectée

Nouveau tableau de bord

Nouveau widget (valeur)

Ouvrir le logiciel
Arduino

Ajouter les bibliothèques DHT sensors et AKERU

Cliquer sur Croquis / Inclure une bibliothèque puis sur Ajouter la bibliothèque.ZIP :

Choisir le répertoire dans lequel se trouve les bibliothèques.

# Une ruche connectée

Pour aller plus loin

Programme avec le logiciel IDE Arduino 1.6.9
Utilisation du réseau SigFox avec le Shield AKENE et abonnement Actoboard activé Exemple avec le capteur DHT22, température et humidité extérieure.

String message = humidite + temperature;

# Une ruche connectée

# Une ruche connectée


Connecter la carte Arduino Uno

Sélection
de la carte

Sélection
du port

Pour aller plus loin

Téléverser le programme dans la carte Arduino Uno et visualiser les données sur le

# Une ruche connectée

Pour aller plus loin

Nombre entier

Nombre à virgule

#include <DHT.h>

#include <Akeru.h>

#define DHTPIN 2

#define DHTTYPE DHT22

DHT dht(DHTPIN, DHTTYPE);

#define TX 5

#define RX 4

Akeru Akeru(RX, TX);

void setup()
{
dht.begin();
Akeru.begin();
}

void loop()
{
int humext = dht.readHumidity();
int tempext = dht.readTemperature();

String humidite = Akeru.toHex(humext); String temperature = Akeru.toHex(tempext); String message = humidite + temperature;

Akeru.sendPayload(message); delay(600000);
}

Lignes à remplacer pour
obtenir un relevé à virgule
Dans le programme DHT22_Sigfox_demo.ino | Sur le tableau de bord Actoboard

# Une ruche connectée

Pour aller plus loin

# Une ruche connectée

Inclure la bibliothèque HX711.

En démarrant le moniteur série (9600 bauds), on obtient la masse.
Lors de l’appui prolongé sur le bouton D6,
la tare se fait.

Pour aller plus loin

725g avec la balance de cuisine. La précision est acceptable pour la pesée de la ruche.

Pour rendre le projet autonome en énergie, nous allons remplacer la carte ARDUINO UNO par la carte OLIMEXINO-328. Elle doit être exploitée comme une Arduino Duemilanove.

Elle intègre :

- Une alimentation permissive de 9 à 30V, ou via USB 5V,
- Un circuit de charge intégré qui permet à la carte de fonctionner sur batterie en l’absence
d’alimentation.
- Un design “industriel”, qui promet une plage de fonctionnement de -25 à +85°C, et une bonne immunité aux interférences,
- La capacité de fonctionner en 5V ou 3.3V.

http://www.conrad.fr/ce/fr/product/1195079/Carte-de-developpement-Olimex-OLIMEXINO-328-1-pcs

Panneau solaire 12V/3W
en alimentation

La carte OLIMEXINO-328, UNIQUEMENT AVEC LE LOGICIEL ARDUINO

# Une ruche connectée

Pour aller plus loin

# Une ruche connectée

Fournisseurs et prix donnés à titre indicatif

Coût moyen pour une ruche connectée toutes options 350€


# Une ruche connectée

Il existe des ruche Dadant 10 cadres en kit, avec la hausse de récolte et tous les cadres.

Pour une application pédagogique, on peut s’orienter vers des pièces détachées.
Un fond de ruche en bois, un corps de ruche, un couvre cadres, un toit tôle.

Une ruche 60 à 100 €

Certaines enseignes de bricolage proposent un rayon apiculture,
quelques fournisseurs de matériel apicole en ligne,
https://www.ets-leygonie.net | http://www.apiculture.net | https://www.icko-apiculture.com

Il est possible d’utiliser un ruchette 5 ou 6 cadres. Dans ce cas, la largeur du auvent est à adapter.

Une ruchette 45 €

Fournisseurs et prix donnés à titre indicatif

# Une ruche connectée


Fournisseurs et prix donnés à titre indicatif

Exemples pour une ruche
en ligne 60 à 80 €

# Une ruche connectée

L’électronique 65€ + connectivité au réseau Sigfox 80 €

Capteur de lumière Grove 3,85€

Capteur de température DS18B20 étanche Grove 8€ https://www.gotronic.fr/art-capteur-de-temperature-grove-101990019-23842.htmhttps://www.gotronic.fr/art-capteur-d-humidite-et-de-t-grove-101020019-18964.htm

Capteur de température/humidité DHT22 Grove 15,50€ https://www.gotronic.fr/art-detecteur-de-niveau-d-eau-grove-101020018-19048.htm

Détecteur de niveau d’eau Grove 3,05€ https://www.gotronic.fr/art-detecteur-de-lumiere-grove-v1-1-101020173-25114.htm

https://www.gotronic.fr/art-lot-de-5-cables-grove-50-cm-22297.htm

5 câbles Grove 50cm 4,10€

Fournisseurs et prix donnés à titre indicatif

https://www.lextronic.fr/capteurs-lumiere-couleur/13946-module-grove-capteur-de-lumiere-p.html

https://www.lextronic.fr/temperature-meteo/28936-module-grove-humidite-temperature.html

https://www.lextronic.fr/temperature-meteo/31559-capteur-de-temperature-ds18b20-format-grove.htmlhttps://www.lextronic.fr/temperature-meteo/28928-detecteur-de-niveau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

https://www.lextronic.fr/cordons-connecteurs/28849-cordons-grove-50-cm.html

# Une ruche connectée

Shield AKENE Sigfox 80 €

https://snootlab.com/lang-fr/shields-snootlab/889-akene-v1-fr.htmlhttps://www.gotronic.fr/art-module-grove-base-shield-103030000-19068.htm

Shield Grove Arduino Uno 9,30€

https://www.gotronic.fr/art-carte-arduino-uno-12420.htm

Carte Arduino Uno 19,50€

Fournisseurs et prix donnés à titre indicatif

https://www.lextronic.fr/cartes-arduino-officielles/2474-carte-arduino-uno-dip-rev3.htmlhttps://www.lextronic.fr/shield-fomat-grove/14174-platine-grove-base-shield-v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

# Une ruche connectée

http://www.robotshop.com/eu/fr/combinateur-capteur-de-charge-v11.htmlhttp://www.robotshop.com/eu/fr/amplificateur-cellule-force-hx711.htmlhttp://www.robotshop.com/eu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

Combinateur de capteur de charge 2€

Amplificateur de capteur de charge 10€

4 capteurs de charge 40€

Option mesure de masse 60 €

Bouton Grove 2€
https://www.gotronic.fr/art-module-bouton-grove-111020000-19010.htm

Fournisseurs et prix donnés à titre indicatif

https://www.lextronic.fr/boutons-claviers/28883-module-bouton-grove-111020000.html

# Une ruche connectée

Carte olimexino 328 21,95€

Option alimentation autonome 50 €

https://www.olimex.com/Products/Duino/AVR/OLIMEXINO-328/open-source-hardware

Batterie LI-PO 4400mAh 8,95€

https://www.olimex.com/Products/Power/BATTERY-LIPO4400mAh/

Chargeur de batterie LI-PO USB 3,95€

https://www.olimex.com/Products/Power/USB-uLiPo/open-source-hardware

Panneau solaire 12V/3,5W 10€

http://www.volumerate.com//product/sunwalk-3-5w-12v-290mah-polycrystalline-silicon-solar-panel-471208 (http://www.volumerate.com/product/sunwalk-3-5w-12v-290mah-polycrystalline-silicon-solar-panel-471208)

https://www.gotronic.fr/art-fiche-alim-fa215-14956.htm

Fiche alim 5,5x2,1 0,30€

Fournisseurs et prix donnés à titre indicatif

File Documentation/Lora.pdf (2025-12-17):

Email : ruche.couesnon@gmail.com
Password Gmail : ruche-couesnon123

The Thing Industry :
https://balanceconnecte.eu1.cloud.thethings.industries/console UserId : rucheducouesnon
Password : Ruche-couesnon123

ESP32
AppEUI 1234561234561234
DevEUI 70B3D57ED8004CE5
AppKey 1D022186E36DDD65691795FE17B7E6C9

Le code :
Initialisation de la radio SX1262 : SX1262 radio = new Module(8, 14, 12, 13);
Pins exactes pour le Wireless Stick V3 : NSS = 8, DIO1 = 14, RST = 12, BUSY = 13

Initialisation du LoRaWAN en OTAA : LoRaWANNode node(&radio, &EU868);
st = node.beginOTAA(joinEUI, devEUI, NULL, appKey);
st = node.activateOTAA();

Join OTAA → demande d’attachement au réseau
Envoi régulier d’un message aléatoire vers TTS randNum = random(50, 101); snprintf(payload, "%d");

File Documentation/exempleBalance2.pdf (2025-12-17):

RuchESIEA; Projet RuchESIEA; Manon FOURNIER Gauthier HEISS

Acquisition de données pour
aider à la conduite d’une ruche

## Table des matières

## Etat de l’art

Introduction

Pour la réalisation de cet état de l’art, nous avons sélectionné les critères qui nous semblaient les plus importants, en partie grâce aux critères de notation du jury du concours mais également en questionnant des apiculteurs. Voici la liste des critères choisis : prix d’achat, prix de l’abonnement, possibilité de faire des relevés de température, d’humidité, du poids de la ruche, fonctionnalité d’antivol, niveaux d’analyse effectuées par le logiciel, type d’alimentation et autonomie et enfin la technologie utilisée pour communiquer. Nous avons rassemblé toutes ces données dans un tableau que vous pouvez consulter à la page 6. Nous avons étudié au total 12 solutions qui nous semblaient variées.

Prix d’achat et d’abonnement

Notre première constatation est simple : le prix des solutions de supervision de ruche déjà existantes sur le marché est très élevé. Le prix moyen des 12 solutions étudiées est de 530€ par unité. Les deux solutions se démarquant sont B-KEEP de Hostabee et BuzzBox de OSBH mais celles-ci ont des fonctionnalités assez limitées. Pour les majorités des produits, il faut ajouter un abonnement allant jusqu’à 72€ par an, comme pour la solution Label Abeille par exemple. Ces prix très élevés pour des produits qui ne sont parfois que gadget les rendent peu attractifs pour des apiculteurs professionnels. Les apiculteurs que nous avons interrogés avaient de forts doutes quant à la rentabilité de ces produits.

Collecte de la température et de l’humidité de la ruche

D’après de nombreux chercheurs¹,3, la température et le niveau d’humidité est un élément clé qu’il est important de mesurer pour s’assurer de la bonne santé d’une ruche. Cependant, peu de solutions le proposent aujourd’hui. Sur les 12 solutions que nous avons étudiées, seules 6 mesurent la température intérieure, dont 2 où il s’agit d’une option payante. Seulement 4 solutions proposent de mesurer l’humidité, dont une où il s’agit d’une option payante. Nous sommes assez étonnés que si peu de produit intègrent la mesure de température et d’humidité car elles peuvent s’implémenter très facilement à l’aide d’un large choix sur le marché de capteurs à faible coût et mesurer des indicateurs importants pour la conduite de la ruche.

Pesée de la ruche

La pesée de la ruche est une fonctionnalité que presque toutes les solutions étudiées possèdent. Pour certaines, c’est même la fonctionnalité phare du produit. Le suivi du poids est très pratique pour suivre en temps réel la production de miel et détecter un essaimage quand il a eu lieu. Cependant, d’après un apiculteur que nous avons interrogé, le suivi du poids n’est pas quelque chose qu’il utiliserait car il n’a aucun moyen d’agir sur la production de miel directement.

Antivol

Certaines sociétés proposent en option un antivol permettant pour certains de géolocaliser la ruche en temps réel si elle est volée. Mais pour d’autres il ne s’agit que d’une fonction gadget qui alerte l’apiculteur quand le poids mesuré par la balance du produit devient subitement très faible. Dans cette implémentation d’antivol, son utilisation concrète semble dénuée d’intérêt. Nous n’avons pas souhaité intégrer ce genre de solution à notre projet car nous pensons que c’est hors catégorie pour le challenge.

Alimentation

Toutes les solutions étudiées sont alimentées par des piles ou batteries plus ou moins remplaçable facilement. L’autonomie d’une charge varie entre 3 mois et 10 ans, cette différence est souvent liée à la fréquence d’envoie des données collectées. Par exemple la solution XLOG Bee de Micro El ne fait qu’un seul envoi de données par jour, ce qui explique son autonomie si élevée de 10 ans. Seulement 4 solutions sur les 12 étudiées proposent d’ajouter un panneau solaire pour ne jamais à avoir à changer de batterie. Ce choix nous semble là encore assez étrange, tant le prix des petits panneaux photovoltaïque a baissé ces dernières années.

Analyse des données

A notre grande surprise, très peu de solutions proposent une analyse poussée des données récoltées. Dans la plupart des cas, les entreprises ne mettent simplement qu’un panneau de contrôle en ligne avec les graphiques des données récoltées. C’est à l’utilisateur de déduire l’état de santé de ses ruches au vu des graphiques.

Aujourd’hui, les technologies d’intelligence artificielle sont présentes partout dans nos vies. De nombreux chercheurs et universitaires se sont penchés sur l’utilisation d’algorithmes d’apprentissage automatique sur des ruches d’abeilles avec des résultats très prometteurs²,4. Grâce à l’analyse des sons émis par les abeilles, il est possible de connaître l’état de santé des ruches. Mais aujourd’hui, aucun produit industriel n’a implémenté les recherches effectuées dans le domaine.

Seul le projet OSBH « Open Source BeeHive » propose une implémentation libre d’un de ces algorithmes. Leur produit BuzzBox Mini est en phase de levée de fonds via un financement participatif à l’heure où nous rédigeons cet état de l’art.

Communication

Les solutions que nous avons étudiées utilisent des protocoles de communication variés. Deux grandes tendances se dégagent : l’utilisation de protocoles dédiés à la communication entre machines comme Sigfox ou LoRA et l’utilisation du protocole GSM. Seules deux solutions ont opté pour l’utilisation du Wi-Fi. Sigfox a l’avantage d’avoir une grande couverture réseau partout dans le monde mais implique un abonnement obligatoire et une faible fréquence d’envois d’informations aux serveurs.

RuchESIEA
Tableau récapitulatif de l’état de l’art des solutions commerciales


Bibliographie

Sites internet des produits étudiés
- HostaBee - https://hostabee.com
- Label Abeille - https://www.label-abeille.org
- BeeZbee - https://www.beezbee.fr
- Connected Beekeeping - https://www.connectedbeekeeping.fr
- BeeGuard - https://www.beeguard.fr
- Optibee - https://www.optibee.fr
- Micro EL - http://www.microel.hr
- Bee2Beep - https://bee2beep.com
- HelpBees - https://ruche-connectee.com
- OSBH - https://www.osbeehives.com
- 3bee - https://www.3bee.com

Articles scientifiques
•

1
Internal Temperatures in a Honey Bee Hive, Millers Homestead LLC, 2016. Consultable sur
http://www.millershomestead.com/NCBroodHeatingCooling.pdf
•

2Monitoring of swarming sounds in bee hives for early detection of the swarming period, divers auteurs, 2008. Consultable sur https://www.researchgate.net/publication/229224190_Monitoring_of_swarming_sounds_in_bee_hives_for_early_detection_of_the_swarming_period (https://www.researchgate.net/publication/229224190_Monitoring_of_swarming_sounds_in_bee_hives_for_early_detection_of_the_swarming_period)
•

3A Smart Sensor-Based Measurement System for Advanced Bee Hive Monitoring, divers auteurs - Università Politecnica delle Marche, 2020. Consultable sur
https://www.researchgate.net/publication/341304426_A_Smart_Sensor-Based_Measurement_System_for_Advanced_Bee_Hive_Monitoring (https://www.researchgate.net/publication/341304426_A_Smart_Sensor-Based_Measurement_System_for_Advanced_Bee_Hive_Monitoring)
•

4On the Importance of the Sound Emitted by Honey Bee Hives, divers auteurs
- Università Politecnica delle Marche, 2020. Consultable sur https://www.researchgate.net/publication/346499008_On_the_Importance_of_the_Sound_Emitted_by_Honey_Bee_Hives (https://www.researchgate.net/publication/346499008_On_the_Importance_of_the_Sound_Emitted_by_Honey_Bee_Hives)

## Notre projet

Notre équipe


Nous sommes Manon Fournier et Gauthier Heiss, deux étudiants en apprentissage à l’ESIEA. Manon est en 4ème année et Gauthier en 5ème année. Nous nous sommes tous les deux spécialisés en cybersécurité. Manon est en alternance chez Quarkslab (https://quarkslab.com/) et Gauthier chez Orange Cyberdefense. (https://orangecyberdefense.com/fr/) Passionnés d’informatique, d’électronique mais aussi d’apiculture, nous sommes ravis de vous présenter notre projet pour ce Challenge Electro-Apicole.

Chronologie
Notre participation à ce challenge ne s’est pas faite dans le cadre d’un projet scolaire mais dans le cadre d’un projet sur notre temps libre. Notre statut d’apprentis ne nous laissant pas énormément de temps, le développement du projet a été assez irrégulier au cours de l’année. Les ruches de notre école ont été installées il y a moins d’un an, nous sommes les premiers à réaliser un projet dessus.

Fin 2020, nous avons réalisé notre état de l’art. Il nous semblait important de le faire avant toute chose pour se rendre compte des produits déjà proposés sur le marché et du statut actuel de la recherche universitaire. C’est suite à cet état de l’art que nous avons choisi les fonctionnalités que nous souhaitions implémenter. Nous avons acheté en conséquence les composants électroniques nécessaires.

De janvier à avril 2021, nous avons été assez inactifs sur le projet faute de temps. Durant cette période, nous avons seulement expérimenté l’utilisation de certains composants que nous avions commandés. C’est en avril 2021 que nous avons entrepris le développement de la partie électronique et du logiciel intégré. Fin avril, nous avons installé nos 10 premiers prototypes sur différentes ruches à Ivry-sur-Seine.

Début mai, nous avons développé le site internet permettant de collecter les données des ruches. Nous avons également installé 10 autres prototypes. C’est ensuite mi-mai que nous avons rédigé ce rapport.

Choix des fonctionnalités et des caractéristiques techniques
Après nos différents échanges avec des apiculteurs et l’état de l’art que nous avons réalisé nous avons décidé de sélectionner les fonctionnalités clés de notre projet. Les voici :
- Mesure de la température et de l’humidité à l’intérieur de la ruche
- Enregistrement audio et analyse avec une intelligence artificielle du son de la ruche
- Mesure du poids de la ruche
- Cartographie internes des cadres (détection du miel, du couvain, etc)
- Chargement de la batterie par panneaux solaires
- Utilisation du Wi-Fi pour communiquer car peu de coût supplémentaire

Nous avons également choisi plusieurs objectifs techniques :
- L’implémentation de toutes ces fonctionnalités devra couter moins de 45€ HT par ruche
- L’autonomie d’une charge de batterie (sans compter les panneaux solaires) avec toutes les fonctionnalités activées devra dépasser 6 mois
- N’utiliser que des technologies connues, bien documentées et très accessibles
- Faire toutes les analyses de l’intelligence artificielle en local dans la ruche et non sur un serveur central

Choix des composants principaux
Voici la liste des composants que nous avons sélectionnés :
Illustration | Nom | Description
| ESP32 Lolin32 lite | Nous avons choisi la plateforme ESP32 pour son rapport fonctionnalités/prix indétrônable. La carte Lolin32 lite intègre sur une petite carte une antenne Wi-Fi et Bluetooth ainsi qu’un contrôleur de charge de batterie pour moins de 2,50€ unité.


| DHT22 | Pour mesurer la température et l’humidité de la ruche, nous avons choisi le DHT22. Son prix est assez élevé (2,80€) par rapport aux autres capteurs mais il est fiable et facile à intégrer.
| Microphone I2S | Pour prendre des mesures audios de la colonie nous avons choisi d’utiliser un microphone I2S. Son prix est très intéressant et il existe plusieurs modèles faciles à intégrer également. La qualité du son est largement suffisante pour nos analyses.


HX711 et 4 cellules de charge 50kg | Grâce à ces modules de pesée à faible coût, nous pouvons mesurer avec une précision de 10g la ruche jusqu’à 200kg.
Panneau solaire USB (type caméra de surveillance) | Ces petits panneaux solaires sont largement assez puissants (3W) pour alimenter tout l’électronique même à faible luminosité. Plusieurs modèles existent sur le marché avec les mêmes caractéristiques. Un seul nous suffit par ruche.
Boitier étanche de dérivation | Nous utilisons ces petits boitiers à faible coût (moins de 2€) car ils sont étanches et assez grands pour contenir tout l’électronique de notre solution.
Capteur de température OneWire 18B20 | Ces petits capteurs sont utilisés pour la cartographie des cadres. Le protocole OneWire permet de brancher l’intégralité des capteurs sur un seul et même câble.
Batterie lithium 18650 3400mAh 3 7V (avec circuit de protection de préférence) | Cette petite batterie, facilement achetable, est suffisante pour alimenter toutes les fonctionnalités pendant 6 mois (si le panneau solaire est absent ou hors service).


Comment ça marche ?

Voici comment fonctionne le micrologiciel que nous avons conçu pour notre boitier et les actions réalisées lorsque toutes les fonctionnalités sont activées :
1. La carte électronique s’allume et lie sa configuration interne (liste des fonctionnalités actives, configuration Wi-Fi, etc).
2. Un enregistrement de 30s d’audio est stocké sur la mémoire interne de la carte électronique.
3. L’intelligence artificielle analyse l’enregistrement audio et en déduit l’état de santé de la ruche. Cette intelligence artificielle est basée sur le projet OpenSource BeeHive. (https://github.com/hiveeyes/osbh-audioanalyzer/tree/df4caf7810c1afb3f4c2074d80d163fbace2183f) Nous l’avons simplement rendu utilisable sur notre carte électronique à faible consommation et réduit ses fonctionnalités à l’essentiel. Ainsi, l’analyse de 30s de son ne prend que 15 à 20s tout en consommant une quantité ridiculement faible d’énergie.


Cadre de ruche avec de multiple capteurs de température OneWire

4. Les mesures des données physiques (température, humidité, poids) sont faites ainsi que celles des cadres. Grâce aux mesures des capteurs de température des cadres, nous pouvons établir une cartographie de ces derniers. En effet, chaque élément du cadre (miel, couvain, etc) est conservé à une température bien précise par les abeilles. Par exemple le couvain est conservé à 35°C à plus ou moins 1°C.
5. La connexion Wi-Fi est établie. Le boitier va ensuite se connecter à un serveur pour lui transmettre toutes les données collectées. Il va également récupérer de potentielles mises à jour du micrologiciel intégré et les installer ou encore exécuter une commande distante comme tarer la balance par exemple.
6. La connexion Wi-Fi est coupée. La carte électronique passe en veille profonde pendant la durée souhaitée entre chaque mesure. Elle va ensuite refaire toutes les actions précédentes en boucle.

Le temps d’exécution de tout ce processus prend moins d’une minute. C’est grâce à cela que nous pouvons assurer une telle autonomie. En mode veille profonde, la carte électronique ne consomme que quelques μA. En fonctionnement, elle consomme environ 60mA avant de se connecter au Wi-Fi et jusqu’à 200mA lorsque la carte est connectée. Ces mesures de consommation peuvent varier en fonction du nombre de capteurs et de la distance au point d’accès Wi-Fi.

Au sujet de la connectivité Wi-Fi, la consommation de données est très limitée, moins de 500 octets par relevé. Si le boitier est situé à proximité d’un point d’accès Wi-Fi, il peut s’y connecter tant que ce dernier supporte la fréquence 2,4Ghz (la plus courante). Si le boitier est en pleine nature, une simple clé 3G avec un petit forfait de données convient. C’est pour cela que nous avons préféré cette solution à l’utilisation du réseau Sigfox que nous jugeons trop couteuse. Nous pensons dans le futur prévoir un boitier tout en un avec une carte SIM libre pour communiquer par SMS. Cela pourrait être, dans certains cas, un petit peu moins coûteux qu’une connexion de données cellulaires.

Solution finale


Voici notre solution finale (hors cadres). Celle-ci est relativement compacte est possède toutes les fonctionnalités que nous avions prévues. Le boitier se place sous la ruche, les 4 modules de pesée se positionnent aux 4 coins de la ruche et le micro peut se placer à l’entrée ou sous la ruche. Nous pensons pouvoir installer 50 boitiers avant le début de l’été. Une partie sera notamment installée à Laval en Mayenne, au second campus de l’ESIEA mais également chez un apiculteur qui nous a conseillé durant la réalisation du projet. Nous sommes déjà à une vingtaine de boitiers déployés.


Préparation de nos boitiers


Installation de nos boitiers au Studio AFL à Ivry sur Seine

Installation de nos cadres connectés à l’ESIEA campus d’Ivry sur Seine

Installation de nos boitiers chez un amateur à Antony


Site internet que nous avons créé pour afficher les données (illustration uniquement)

## Mise en œuvre de notre solution

Introduction

La liste de nos fonctionnalités étant large et pas nécessairement utile à tous, nous avons divisé tout notre projet en modules. Ainsi, pour la suite des instructions et des composants à acheter, nous vous indiquerons dans quel cas ils seront nécessaires par rapport à vos besoins. Les modules sont les suivants :
- Module de base avec analyse audio (obligatoire)
- Module de pesée
- Module de température et d’humidité de la ruche
- Modules de cadres pour cartographie

Eléments à acheter

Voici la liste des composants à acheter pour pouvoir mettre en œuvre notre solution. Si un lien devient inaccessible ou un produit indisponible, n’hésitez pas à nous contacter. Veuillez noter que les prix renseignés sont ceux tels que présentés le 14/05/2021, ils sont susceptibles d’évoluer avec le taux de change. Certaines pièces sont imprimées en 3D. Les plans sont fournis avec nos autres travaux. Vous pouvez utiliser n’importe quel matériau vous-même mais si vous préférez une impression 3D et que vous n’avez pas accès à une imprimante, l’Openlab ESIEA se propose de vous vendre les pièces imprimées à prix coutant. C’est le prix qui est indiqué pour ces pièces.

- Module de base avec analyse audio (obligatoire) – 7,32€
Illustration | Nom | Prix | Lien
| ESP32 Lolin32 lite | 2,30€ | Aliexpress.com (https://fr.aliexpress.com/item/4000038780903.html?spm=a2g0s.9042311.0.0.27426c37vAZCrn)


| Porte batterie 18650 | 0,30€ | Aliexpress.com (https://fr.aliexpress.com/item/4000859859685.html)
| Batterie 18650 3,7V 3400mAh | 2,00€ | Aliexpress.com (https://fr.aliexpress.com/item/32324914059.html)
| Boitier étanche | 1,19€ | Leroymerlin.fr (https://www.leroymerlin.fr/produits/electricite-domotique/rallonge-multiprise-enrouleur-et-cable-electrique/accessoires-de-connexion-boite-de-derivation/boite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)
| Microphone I2S | 1,53€ | Aliexpress.com (https://fr.aliexpress.com/item/32961274528.html)
| Cache microphone imprimé en 3D | 0,30€ | Openlab ESIEA

- Module de pesée – 4,59€
Carte HX711 + 4 cellules de charges de 50kg | 3,69€ | Aliexpress.com (https://fr.aliexpress.com/item/32968926628.html?spm=a2g0s.9042311.0.0.2f226c37gmnhVU)
4 supports imprimés en 3D | 0,90€ | Openlab ESIEA


- Module de température et d’humidité – 3,68€
DHT22 | 2,81€ | Aliexpress.com (https://fr.aliexpress.com/item/32523611214.html?spm=a2g0s.9042311.0.0.2f226c37gmnhVU)
1 résistance 4,7kΩ | 0,42€ | Aliexpress.com (https://fr.aliexpress.com/item/1005002596515333.html) (lot, « 4.7 »)
Cache imprimé en 3D | 0,45€ | Openlab ESIEA


- Modules de cadre pour cartographie – 0,42€ + 2,34€ par cadre
Capteur de température OneWire 18B20. Il en faut 9 par cadre. | 0,26€ | Aliexpress.com (https://fr.aliexpress.com/item/32832385673.html)
1 résistance 4,7kΩ (une seule est requise, quelque soit le nombre de cadre) | 0,42€ | Aliexpress.com (https://fr.aliexpress.com/item/1005002596515333.html) (lot, « 4.7 »)


- Alimentation solaire
Panneau solaire
étanche micro-USB
3W
14,40€ | Aliexpress.com (https://fr.aliexpress.com/item/1005002511257139.html) (« only solar panel »)

- Outillage électronique à avoir
- Fer à souder pour électronique
- Etain pour soudure
- Fil électrique étamé fin
- Connecteurs Dupont mâle-femelle
- Gaines thermo rétractables
- Pince coupante
- Pince à dénuder
- Câble électrique avec 3 fils (pour les cadres)

Montage de l’électronique

Toutes les instructions de montage présentes ci-dessous vous sont également proposées en vidéo commentée. Comme pour les articles à acheter, cette partie sera divisée par rapport aux différents modules. Vous trouverez ci-dessous un condensé de la vidéo de montage avec les schémas et quelques explications. Ne seront montrés sur les schémas que les branchements d’un module à fois, les autres seront masqués.

- Module de base avec analyse audio (obligatoire)

A mettre dans le boitier étanche

Schéma de branchement du module de base

Voici les branchements à effectuer pour le module de base. Pour souder les fils du porte batterie à la carte électronique, vous devez utiliser une pince pour retirer le connecteur plastique blanc. Veuillez également noter que les connecteurs « 3V » (fils rouge) et « G » (fil noir) seront réutilisé pour les autres modules, il ne faut pas donc tout de suite mettre de gaine thermo rétractable. Le reste des fils peuvent être directement soudés.

N’oubliez pas de prévoir des fils assez longs pour pouvoir déporter le micro à la position souhaitée lors de l’installation du boitier dans la ruche. Il est déconseillé de mettre la batterie dans le porte batterie tant que l’assemblage de tous les modules n’est pas terminé.


- Module de pesée

Schéma de branchement du module de pesée

Les fils présents sur les charges de poids peuvent être assez fragiles, il faut donc les manier avec précaution. Il faut également prévoir de rallonger les fils rouges des cellules pour avoir assez de marge lors du placement sous la ruche. Enfin, les fils des cellules ont tendance à s’emmêler assez vite, faites attention.

- Module de température et d’humidité

Schéma de branchement du module de température et d’humidité

A mettre dans le boitier étanche

A mettre dans le boitier étanche

- Modules de cadre pour cartographie

A mettre dans le boitier étanche

Schéma des modules de cadre pour cartographie

Le schéma ci-dessus présente comment brancher une série de 4 capteurs mais vous pouvez en rajouter autant que nécessaire. Il faut mettre 9 capteurs par cadre et les cadres peuvent être branchés directement les uns après les autres en suivant la notice de branchement. Il suffit ensuite d’accrocher les capteurs au cadre et de le cirer.


Assemblage des capteurs OneWire sur un cadre

Nous avons essayé plusieurs techniques pour assembler les capteurs de températures OneWire sur des cadres. La manière la plus efficace que nous avons trouvé consiste à accrocher les capteurs aux supports des cadres et de faire 3 rangés de 3 capteurs.


Nos cadres de test dans des ruches Faites attention à bien tendre des fils pour ne pas gêner les abeilles comme sur la photo de gauche. Ainsi les abeilles pourront bien construire comme sur la droite.

- Panneau solaire
Pour connecter le panneau solaire rien de plus simple, il suffit de faire passer le câble micro-USB au travers du boitier étanche et de le brancher sur la carte électronique. Au soleil, si une batterie est branchée une LED bleue sur la carte devrait s’allumer et rester statique. Sinon, cette LED bleue devrait clignoter. Vous devriez remarquer que même à une faible luminosité le panneau solaire suffit à alimenter le boitier.

Préparation du logiciel intégré

Pour la préparation du logiciel intégré, vous devez d’abord vous connecter à la plateforme RuchESIEA. Vous avez alors deux options :
1. Installer vous-même une instance du site RuchESIEA sur votre ordinateur ou serveur
2. Utiliser gratuitement l’instance de notre site RuchESIEA hébergé par l’ESIEA à l’adresse https://ruch.esiea.fr (conseillé)
Dans le premier cas, vous devez vous munir du code source du site RuchESIEA qui est joint avec ce rapport. Les instructions d’installation sont dans le fichier « README ». Une fois installé, vous pouvez vous inscrire sur votre plateforme et suivre la suite des instructions.
Dans le deuxième cas, vous n’avez qu’à créer un compte à l’adresse suivante https://ruch.esiea.fr/register puis suivre la suite des instructions.

Une fois connecté sur la plateforme web, il faudra cliquer sur « Ajouter une nouvelle ruche ». Il vous faudra alors lui donner un nom et une photo facultative. Une fois créée, vous pouvez cliquer dessus. Vous arriverez alors sur la page d’information de la ruche. Une clé API sera présente, vous devez la noter, vous en aurez besoin plus tard dans les instructions. Vous pouvez également télécharger la dernière version du firmware en cliquant sur le bouton dédié si vous essayez notre solution en dehors du contexte du challenge. Sinon, le micrologiciel est joint avec le rapport.

Le firmware se présente sous la forme d’un dossier compressé ZIP, vous devez l’extraire à l’emplacement de votre choix. Une fois extrait, vous devez installer le logiciel Arduino, téléchargeable ici : https://www.arduino.cc/en/software. Une fois installé, ouvrez le fichier « RuchESIEA.ino » présent dans le dossier du firmware extrait précédemment.

Dans un premier temps, nous allons ajouter la configuration de base de la carte électronique dans le logiciel Arduino. Rendez-vous dans Fichier > Préférences. Dans le champ « URL de gestionnaire de cartes supplémentaires », inscrivez l’URL suivante et

validez : | https://raw.githubusercontent.com/espressif/arduino-esp32/gh-
pages/package_esp32_index.json (https://raw.githubusercontent.com/espressif/arduino-esp32/gh-pages/package_esp32_index.json)
Une fois cela fait, rendez-vous dans Outils > Type de carte > Gestionnaire de cartes. Dans la zone de texte, rentrez « ESP » est installez le paquet proposé. Veuillez ensuite patienter que le tout s’installe. Vous pouvez ensuite fermer la fenêtre d’installation. Dans le menu Outils > Type de carte, sélectionnez en bas la carte « WEMOS Lolin32 lite ».

Nous allons maintenant installer les bibliothèques nécessaires. Rendez-vous dans le menu Outils > Gérer les bibliothèques. Vous aurez besoin de chercher et installer les bibliothèques suivantes. Attention, les résultats de recherche sont simplement triés par ordre alphabétique.
- « esp32_ftpclient » by Leonardo Bispo
- « LittleFS_esp32 » by lorol
- « HX711 » by Rob Tillaart
- « OneWire » by Jim Studt, Tom Pollard, Robin James, …
- « DHT sensor library » by Adafruit
- « Adafruit Unified Sensor » by Adafruit

Une fois toutes les bibliothèques installées, vous devriez être en mesure de compiler le micrologiciel en cliquant sur « vérifier » (bouton en haut à gauche ✓). Si une erreur se produit, vérifier que toutes les bibliothèques mentionnées ci-dessus sont installées et que d’autres avec un nom similaire n’ont pas été installées par erreur.

Il est maintenant l’heure de configurer votre boitier par rapport à votre réseau Wi-Fi et les modules que vous avez montés. Sur le logiciel Arduino, rendez-vous dans l’onglet « config.h ». Dans la partie « Modules » en haut du fichier. Vous pouvez écrire « false » (pour désactiver) ou « true » (pour activer) chaque fonctionnalité. Voici à quoi chaque ligne correspond :
- FTP_UPLOAD : mettre en ligne les fichiers audios enregistré par votre boitier, à laisser sur « false » sauf si vous voulez écouter l’audio de votre ruche.
- ONE_WIRE : module de cartographie des cadres
- AI : intelligence artificielle d’étude des sons de la ruche
- DHT22 : module de température et d’humidité de la ruche
- SCALE : module de pesée
- OTA : mise à jour automatique à distance, à désactiver pour le challenge

Plus bas dans le fichier de configuration, cherchez la ligne « API_KEY ». Veuillez remplacer le texte à l’intérieur des guillemets par la clé API que vous avez noté plus tôt. Enfin, aux lignes « WIFI_SSID » et « WIFI_PASSWORD », vous devez entrer à l’intérieur des guillemets le nom de votre réseau Wi-FI et son mot de passe. A noter que si vous êtes dans une université ou une entreprise avec une authentification 802.1x, vous devez utiliser « WIFI_LOGIN » pour inscrire le nom d’utilisateur, sinon laissez vide ce champ.

Si vous avez vous-même installé votre instance du site RuchESIEA, vous devez également aller à la ligne « HTTP_SERVER » pour remplacer ruch.esiea.fr par votre adresse (IP ou URL).

Vous pouvez maintenant brancher la carte électronique du boitier sur votre ordinateur via le port micro-USB. Une fois branchée, attendez quelques instants que votre ordinateur la détecte puis cliquez sur « téléverser » (bouton en haut à gauche ➔).

Le micrologiciel est maintenant sur votre carte électronique. Pour vous assurer que tout fonctionne bien, vous pouvez ouvrir le « Moniteur série » (bouton en haut à droite). Une fenêtre va s’ouvrir. Elle contient tous les messages que la carte envoi pour vous informer de son fonctionnement. Si rien n’apparait et que la fenêtre est blanche, vous pouvez appuyer sur le petit bouton « reset » présent sur la carte électronique entre le port micro-USB et le connecteur pour batterie.

Si une erreur survient, n’hésitez pas à nous contacter, nous serons ravis de pouvoir vous aider !

Guide d’utilisation

Une fois que votre boitier assemblé est prêt, il ne vous reste plus qu’à l’installer dans votre ruche. Pour cela, positionnez les 4 cellules de pesée en dessous des 4 coins de la ruche. Il est important que le poids repose uniquement dessus. Posez le microphone à l’entrée ou en dessous de la ruche au niveau des aérations. Assurez-vous que la batterie est bien connectée. Vous pouvez maintenant fermer le boitier et attendre que les mesures apparaissent. Par défaut, le relevé se fait toutes les heures. Si vous voulez forcer un relevé, vous n’avez qu’à appuyer sur le bouton reset de la carte électronique (entre les connecteurs USB et de batterie). Si vous voulez que le relevé se fasse à une fréquence différente, vous pouvez modifier la ligne « TIME_TO_SLEEP » et inscrire la durée en seconde.

Pour accéder à vos données, rendez-vous sur le site RuchESIEA mentionné plus tôt. Vous aurez alors accès aux graphiques de température, d’humidité et de poids mais également aux résultats d’analyse de l’intelligence artificielle et de la cartographie des cadres si vous l’avez activé.

Problèmes courants – guide de réparation

Problème | Solution
La carte n’envoie pas de données au site internet | Vérifiez en connectant le boitier à votre ordinateur et en ouvrant le moniteur série que la carte arrive bien à se connecter à votre réseau Wi-Fi.
Un fil de balance s’est cassé | Pas de panique, il suffit de dénuder et ressouder le fil cassé. Une gaine thermo rétractable suffit à consolider le tout.
La carte envoyait des données mais ne le fait plus subitement | Vérifiez qu’elle arrive toujours à se connecter au Wi-Fi et vérifiez la charge de la batterie. Si vous avez un voltmètre, la tension de la batterie doit se situer entre 3,2 et 4,7V. Branchez la carte en USB pour la recharger si besoin.
Les mesures sont délirantes | Vérifiez que tous les capteurs sont bien connectés/soudés. N’hésitez pas à brancher la carte à votre ordinateur pour obtenir les relevés de données brutes.
La mesure de poids est nulle | Vérifiez que le poids de la ruche repose bien sur la pointe métallique des cellules de poids et qu’aucun fil n’est cassé.
Les résultats de l’intelligence artificielle ne reflètent pas l’état de santé de ma ruche | L’intelligence artificielle est encore à l’état de prototype. N’hésitez pas à nous signaler tout résultat étrange pour nous permettre de l’améliorer.

## Conclusion

Nous sommes ravis d’avoir pu participer à ce challenge et espérons que nos travaux plairont. Nous avons travaillé sur ce projet avec passion.

Nos projets pour l’avenir

Pour rendre ces technologies accessibles au plus grand nombre d’apiculteurs possibles, nous souhaitons continuer à travailler dessus. Nous aimerions l’améliorer dans un premier temps avec les retours que nous aurons du challenge. Mais surtout, nous voudrions transformer ce prototype en un vrai produit industriel et le produire à grande échelle à l’aide d’une campagne de financement participatif.

Nous contacter

Si vous avez des questions ou des remarques, nous serions ravis de pouvoir discuter avec vous. Vous trouverez ci-dessous nos adresses emails.

- Manon FOURNIER – fournier@et.esiea.fr
- Gauthier HEISS – heiss@et.esiea.fr

Remerciements

Même si notre équipe n’est composée officiellement que de deux étudiants, de nombreuses personnes nous ont aidés de prêt ou de loin. Nous souhaitions les remercier ici.

- Loïc Roussel, directeur général du groupe ESIEA
- Sophie Poirier, responsable associations et vie étudiante du groupe ESIEA
- Bastien Quelen, directeur technique du groupe ESIEA
- Frédéric Lebard, directeur du Studio AFL à Ivry sur Seine
- Julien, Apiculteur à Laval
- Alexandre, Charles et Mathis, étudiants à l’ESIEA
- Les organisateurs de ce concours et leurs partenaires pour nous avoir permis de réaliser ce projet :


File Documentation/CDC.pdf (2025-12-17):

BALANCE CONNECTEE POUR SUIVI RUCHES

CAHIER DES CHARGES

Objectif : développer une balance connectée low-tech permettant de suivre en direct la prise de poids de la ruche à distance sur une application directement consultable sur téléphone.

Caractéristiques techniques :

- La balance doit être étanche (IP67), facile à installer et déplacer - notamment lors des transhumances (légèreté)
- La précision de la pesée doit être de +/- 100gr minimum et le calibrage assuré
- Le poids maximum pour 1 ruche est de 100kg (ou 400kg si 4 ruches pesées en simultané)
- La batterie idéalement pourrait être rechargeable mais sinon, les piles utilisées doivent pouvoir fonctionner a minima 12 mois
- Les composants doivent facilement pouvoir être remplaçables en cas de panne (disponibilité stocks pièces) – fabrication française.
- Transmission des données : réseau à préciser ? Sigfox, 3G/4G, NB-iot
- Une donnée toutes les heures est suffisante
- Développement de l’application permettant d’accéder aux données
- Option 1 : puce GPS intégrée pour localiser la balance
- Option2 : voir pour une balance permettant de connecter les données de 4 ruches simultanément (disposées sur une même palette), pour en ressortir un poids moyen.

2 tarifs à établir

- Le prix de la balance
- Le prix de l’abonnement mensuel de la transmission des données

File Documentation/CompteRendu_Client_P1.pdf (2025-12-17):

### Bilan du projet : Balance connectée pour le suivi des ruches

Ce compte rendu couvre les activités réalisées entre septembre et octobre 2025.

### Les objectifs principaux étaient l’intégration du module LoRa et la conception

mécanique de la balance.

### 1. Tâches accomplies

a. Sélection et réception des composants
b. Étude et tests de la carte électronique utilisée pour calculer le poids
c. Validation du capteur de gravité et calcul de masse
d. Expérimentation sur un petit exemple déjà fait pour la balance
e. Conception mécanique du balance (sans réalisation physique seulement théorique)
f. Développement du gateway Lora et module du calcul (carte electronique responsable pour le calcule du poids avec vérification des valeurs et envoie des données)
g. Développement de l’application (Fonctionnalité toujours basique)
h. Test du module GPS individuellement.

### 2. Tâches en cours

a. Réalisation mécanique de la balance.
b. Affichage des messages de poids en temps réel.
c. Intégration du GPS avec la carte électronique de LoRa.

### 3. Remarque connectivité

La mise en place de la communication Lora signifie que chaque balance communique localement avec un gateway (à acheter) qui transmet tout vers un serveur utilisé par l’appli. L’échange gateway/serveur nécessite une connexion internet disponible si la zone est couverte par lora et si ce n’est pas le cas il faut couvrir la zone avec un boitier 4G. Cette solution reste moins coûteuse qu’une communication 3G/4G qui consomme + et qui nécessite une sim par balance donc des frais d’abonnement récurrents. La solution LoRa revient à un investissement initial (une passerelle (gateway), et un module LoRa par balance) et aucun coût d’abonnement mensuel, ce qui la rend idéale pour un usage longue durée et autonome.

Conclusion
Les composants ont été sélectionnés, testés et validés, et les premières expérimentations confirment la faisabilité technique du système. Les prochaines étapes visent à finaliser l’intégration du dispositif, à développer l’application et à réaliser des essais en conditions réelles.

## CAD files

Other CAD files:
Conception Mécanique/reine1.CATPart
Conception Mécanique/reine2.CATPart

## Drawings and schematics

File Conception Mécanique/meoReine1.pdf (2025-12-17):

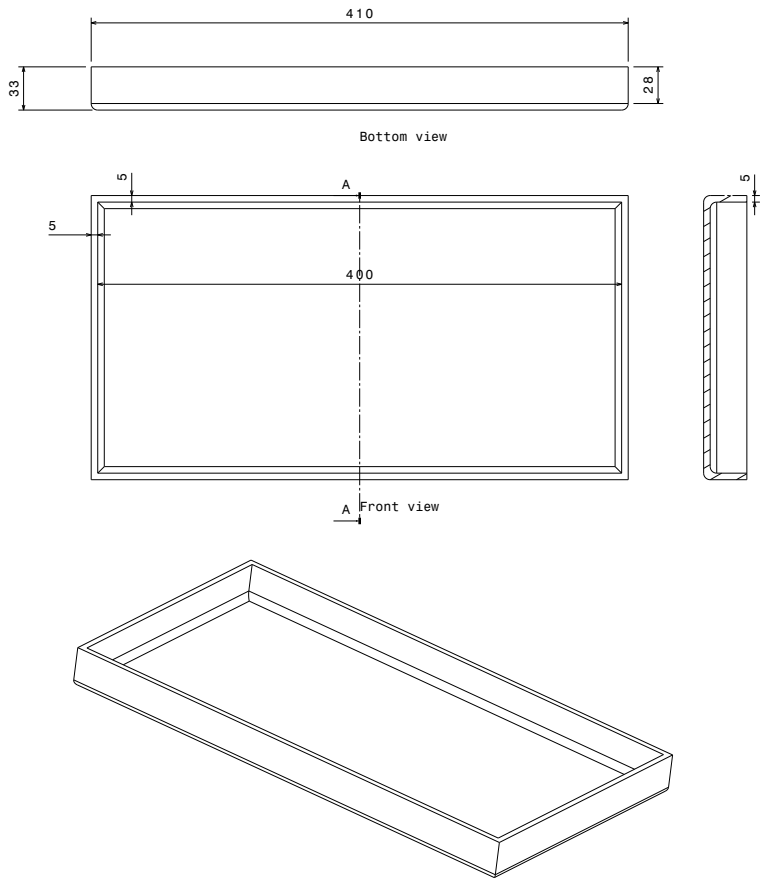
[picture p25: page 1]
Front view; Bottom view

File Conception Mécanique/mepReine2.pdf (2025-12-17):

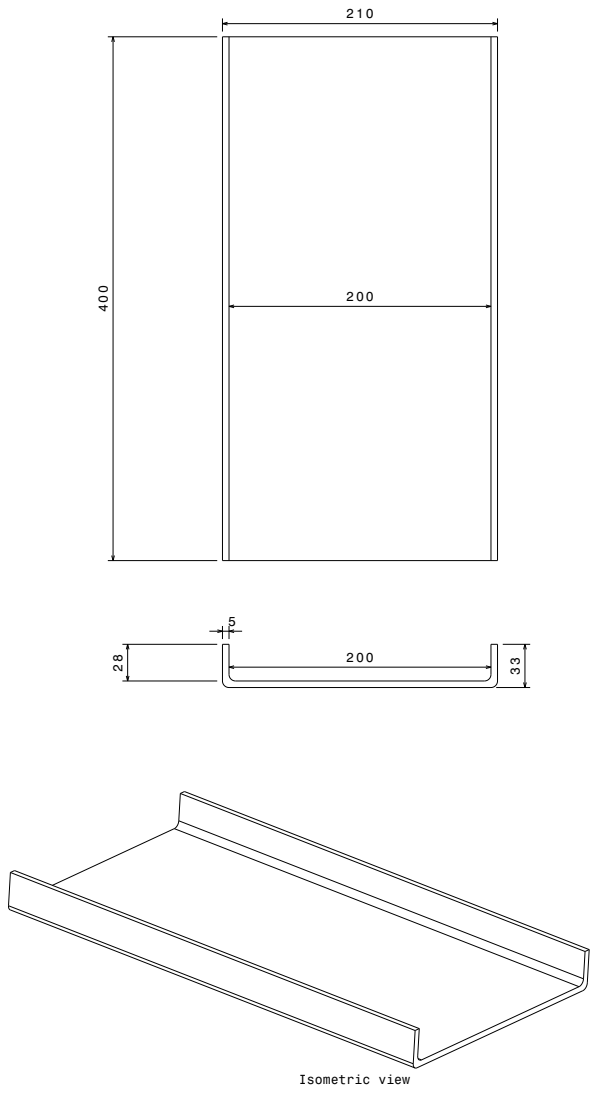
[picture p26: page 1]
Isometric view

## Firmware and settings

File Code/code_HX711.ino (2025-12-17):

#include "HX711.h"   
// Bibliothèque HX711 permettant de communiquer
// avec le module HX711 (amplificateur + convertisseur ADC)

// ================== CONNEXIONS HX711 -> ARDUINO UNO ==================
// DT  (DOUT) : sortie données du HX711 vers l'Arduino
// SCK        : horloge envoyée par l'Arduino au HX711
#define DT  3     // Broche numérique 3 de l'Arduino connectée à DOUT
#define SCK 2     // Broche numérique 2 de l'Arduino connectée à SCK

// Création de l'objet HX711
HX711 scale;

// ================== FACTEUR DE CALIBRATION ==================
// Ce facteur permet de convertir la valeur brute du HX711
// en une valeur réelle de poids (en grammes).
// Il dépend de la cellule de charge utilisée.
float calibration_factor = -459.542;

void setup() {
  // Initialisation de la communication série
  // Permet d'afficher les résultats sur le moniteur série
  Serial.begin(9600);

  // Initialisation du HX711 avec les broches définies
  scale.begin(DT, SCK);

  // Application du facteur de calibration
  scale.set_scale(calibration_factor);

  Serial.println("=== BALANCE HX711 ===");
  Serial.println("Retirez tout poids de la balance...");
  delay(2000);

  // Mise à zéro (tare)
  // Permet de considérer le poids actuel comme référence zéro
  scale.tare();
  Serial.println("Tare OK !");
  Serial.println();
}

void loop() {

  // Vérifie si le HX711 est prêt à envoyer des données
  if (!scale.is_ready()) {
    Serial.println("ERREUR : HX711 non detecte !");
    delay(500);
    return;
  }

  // ================== LECTURE BRUTE ==================
  // Lecture directe du convertisseur ADC (valeur brute)
  // Utile pour le debug ou la calibration
  long brut = scale.read();

  // ================== LECTURE CALIBRÉE ==================
  // Lecture moyenne de 5 mesures, convertie en grammes
  float poids_g = scale.get_units(5);

  // Conversion du poids en kilogrammes
  float poids_kg = poids_g / 1000.0;

  // ================== AFFICHAGE DES RÉSULTATS ==================
  Serial.print("Brut : ");
  Serial.print(brut);
  Serial.print(" | Poids : ");
  Serial.print(poids_g, 2);
  Serial.print(" g  |  ");
  Serial.print(poids_kg, 3);
  Serial.println(" kg");

  // Délai entre deux mesures
  delay(300);
}

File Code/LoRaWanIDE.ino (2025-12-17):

// ESP32-S3 Wireless Stick SX1262 OTAA example (EU868)
// Pins: NSS=8, DIO1=14, RST=12, BUSY=13

#include <RadioLib.h>

// init module
SX1262 radio = new Module(8, 14, 12, 13);

// Select the region band
LoRaWANNode node(&radio, &EU868);


uint64_t joinEUI = 0x1234561234561234;        // AppEUI/JoinEUI
uint64_t devEUI  = 0x70B3D57ED8004CE5;        // DevEUI

uint8_t  appKey[16] = {
  0x1D, 0x02, 0x21, 0x86, 0xE3, 0x6D, 0xDD, 0x65, 0x69, 0x17, 0x95, 0xFE, 0x17, 0xB7, 0xE6, 0xC9
};


void setup() {
  Serial.begin(115200); while(!Serial) {}

  int16_t st = radio.begin();
  if (st != RADIOLIB_ERR_NONE) { Serial.println("radio.begin failed"); while(true){} }

  // LoRaWAN 1.0.x: pass NULL for NwkKey
  st = node.beginOTAA(joinEUI, devEUI, NULL, appKey);
  if (st != RADIOLIB_ERR_NONE) { Serial.println("beginOTAA failed"); while(true){} }

  st = node.activateOTAA();                       // perform join
  // if (st < RADIOLIB_ERR_NONE) { Serial.println("activateOTAA failed");Serial.println(st); while(true){} }
  Serial.print("activateOTAA status = ");
  Serial.println(st);

  delay(5000);

  node.setADR(true);                              // let network manage DR
  Serial.print("DevAddr: 0x"); Serial.println(node.getDevAddr(), HEX);
}

void loop() {
  int randNum = random(50, 101);
  char payload[8];
  snprintf(payload, sizeof(payload), "%d", randNum);

  // Unconfirmed uplink on FPort 1 (avoid FPort 0)
    int16_t st = node.sendReceive(payload, 1, false);
  Serial.print("sendReceive: "); Serial.println(st);

  // Optional: ask for link quality to verify end-to-end path
  node.sendMacCommandReq(RADIOLIB_LORAWAN_MAC_LINK_CHECK);
  uint8_t margin=0, gws=0;
  if (node.getMacLinkCheckAns(&margin, &gws) == RADIOLIB_ERR_NONE) {
    Serial.print("LinkCheck margin="); Serial.print((int)margin);
    Serial.print(" gw="); Serial.println((int)gws);
  }

  //duty cycle
  uint32_t waitMs = max<uint32_t>(node.timeUntilUplink(), 10000);
  delay(waitMs);
}

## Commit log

2025-12-17 cdc, cr client, codes lora, read me de base
2025-12-17 ajout fichiers conception meca
    [reine1.CATPart, reine2.CATPart]
2025-12-17 ajouts de docs / code
2025-12-17 ajout de la doc capteur
